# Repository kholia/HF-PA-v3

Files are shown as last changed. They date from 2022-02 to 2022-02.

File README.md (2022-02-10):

### HF-PA-v3

VU3CER's Robust `Class-C / Class-D HF PA` for https://github.com/kholia/Easy-Digital-Beacons-v1
project for the 20m band.

This design aspires to be the standard mW-to-QRP-Gallon HF PA in the ~600 INR
(8 USD) design space.

Design Constraints:

- PCB is to be homebrewed.

- PCB is single-sided - only one layer (side) is available for routing.

- IRF510 MOSFET needs to be on an edge to allow usage of heatsinks.

- Typical external linears (e.g. `PA150 HF Linear Amp`) need 2W minimum to
  function. So we need a minimum of 2W of RF output from our design.

- Minimal part count is strongly preferred. Low cost, and ease of availability
  are strong driving and deciding factors.

  The cost of this HF-PA-v3 system is less than one RD16HHF1 MOSFET ;)

- Reproducibility is a MUST! We focus a lot on this aspect by documenting each,
  and every detail possible.

- Repairability in the field is a MUST!

  Dhiru's finding: Repairing homebrewed PCBs is so much easier, and fun than
  reworking commercial `lead-free` PTH PCBs.

- No moving mechanical parts are allowed in the design - this rules out usage
  of (failure-prone) active cooling options like fans.

Input: Few milliwatts is fine. Note: Si5351's output is around 8-10mW.

Output: 5W+ @ 28v for the 20m band (`QRP Gallon achieved!`) with around ~42%
efficiency. 4.25W+ @ 24v for 20m band (14 MHz) using a single IRF510 with ~33%
to ~43% efficiency. Solid 3W+ at 19v with less than 500mA of total current
consumption. Solid 4W+ at 22v with less than 500mA of total current
consumption. More output is possible via a bit more gate biasing voltage +
increased PA voltages (>= 29v). The `Easy-Digital-Beacons-v1` system itself
consumes 2.49W when operating in the `Beacon Mode`. In comparison to this `v3
HF PA`, https://github.com/kholia/HF-PA-v2/ is more efficient (@ 14 MHz) but is
not as robust. In comparison, ICOM IC-705 efficiency is around 24% - It
consumes around 1.5A @ 13.8v to output 5 watts - Of course, ICOM's PA is a
linear one (with known low efficiencies) whereas ours is a switching one.

Robustness check: The PA works fine with 100% duty cycle for more than 8 hours!
In real-life, WSPR defaults to using ~2-minute TX intervals every 10 minutes.
FT8 is naturally gapped every ~15 seconds, and so on. We have also run FT8 on
this HF PA for more than a day at a time. The whole `HF PA v3` system is
thermally super stable.

Note 1: The output power is software controllable (via `PWM grounding`) for
flexibility.

Note 2: The idea behind making these (and my other) design notes publicly
available is to deliver REPRODUCIBLE, flexible, home-brewable, standardized,
reasonable, and cost-effective solutions for some common problems. I include
many references, simulations, and notes in my projects to enable you to do your
own (better) designs - do share them ;)

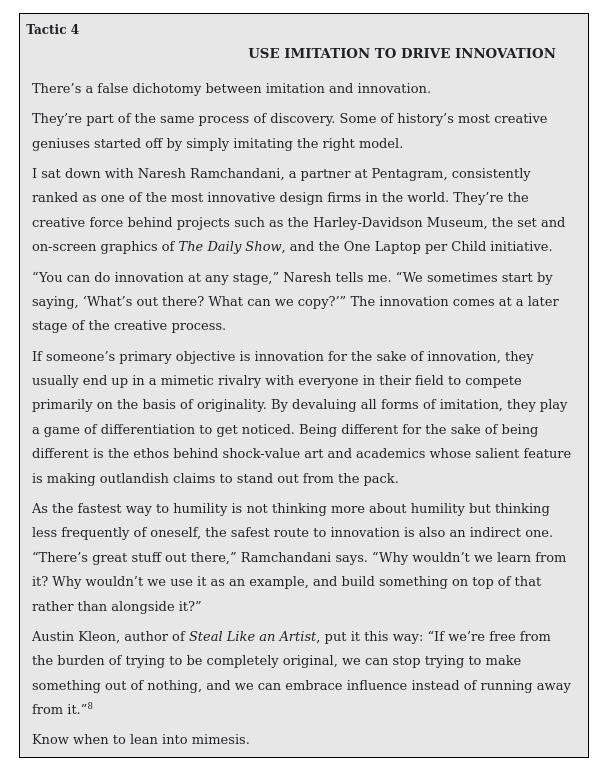
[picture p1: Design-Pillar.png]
Design Pillar


(Image Credit: `Wanting` book by Luke Burgis)

Note 3: All screenshots are clickable and zoomable.

Note 4: Use the `HF-PA-v3-No-Regulator` PCB version included in this
repository. This version doesn't need the 7805 linear regulator.

Please see the older https://github.com/kholia/HF-PA-v2 project for the
power-supply (over-current protected), and LPF designs.

(26-September-2021 UPDATE): [A multi-band (40-20-17-15) version of this PA is now available](https://github.com/kholia/HF-PA-v4/)!

Schematic:

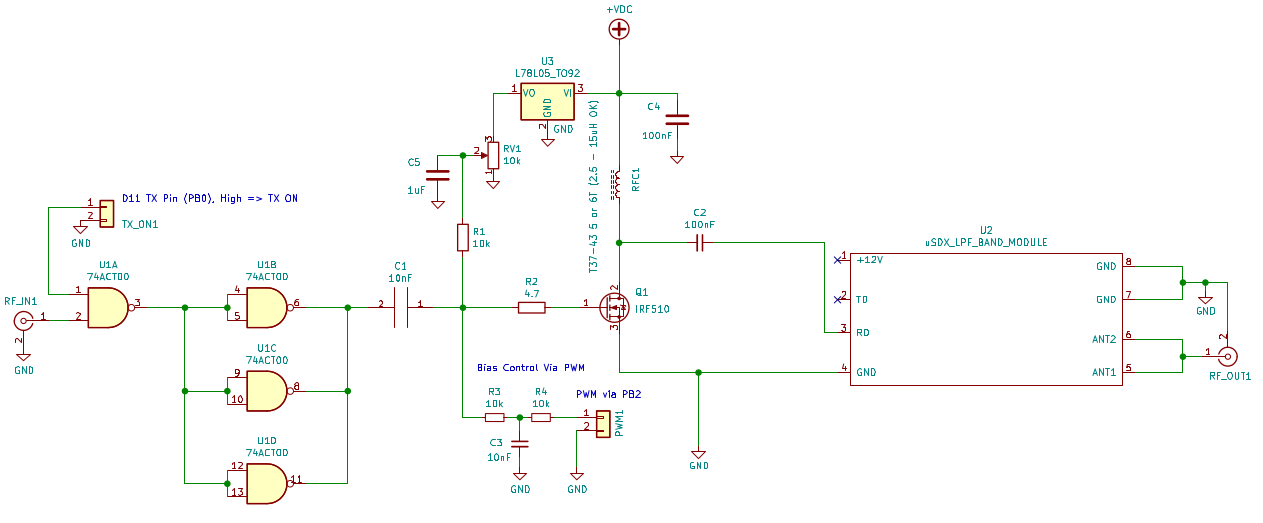
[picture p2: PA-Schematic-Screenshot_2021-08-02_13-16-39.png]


PCB renderings:

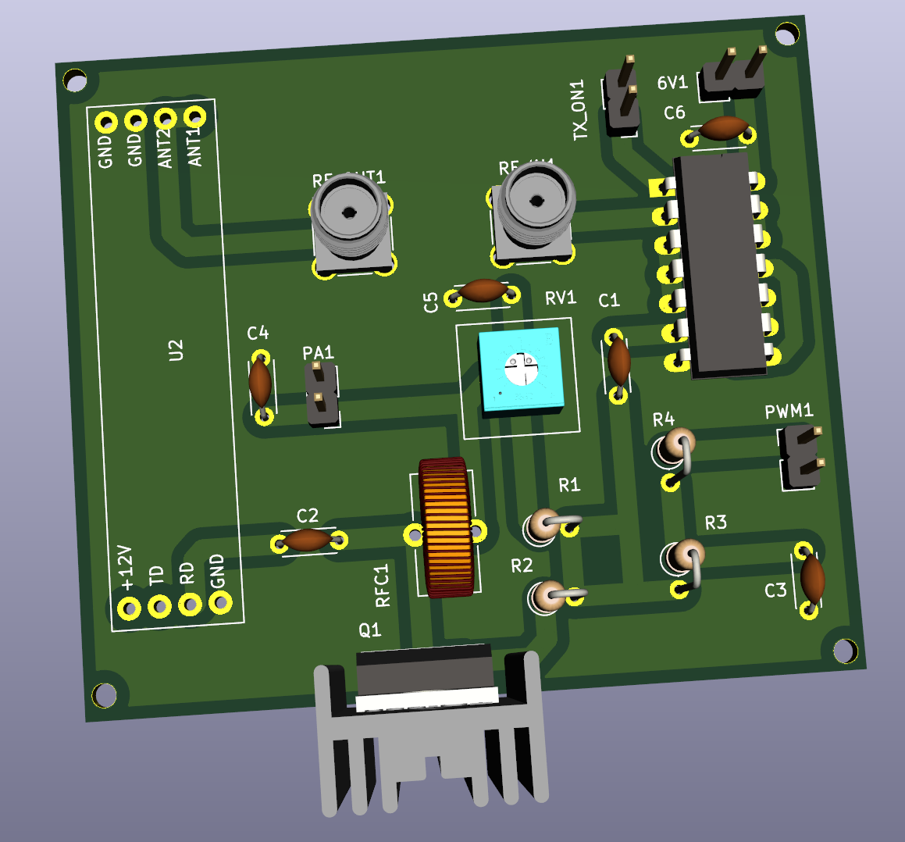
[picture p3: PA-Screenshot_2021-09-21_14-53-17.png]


Pics (or it didn't happen):

5W RF Output @ 28v

Power consumption

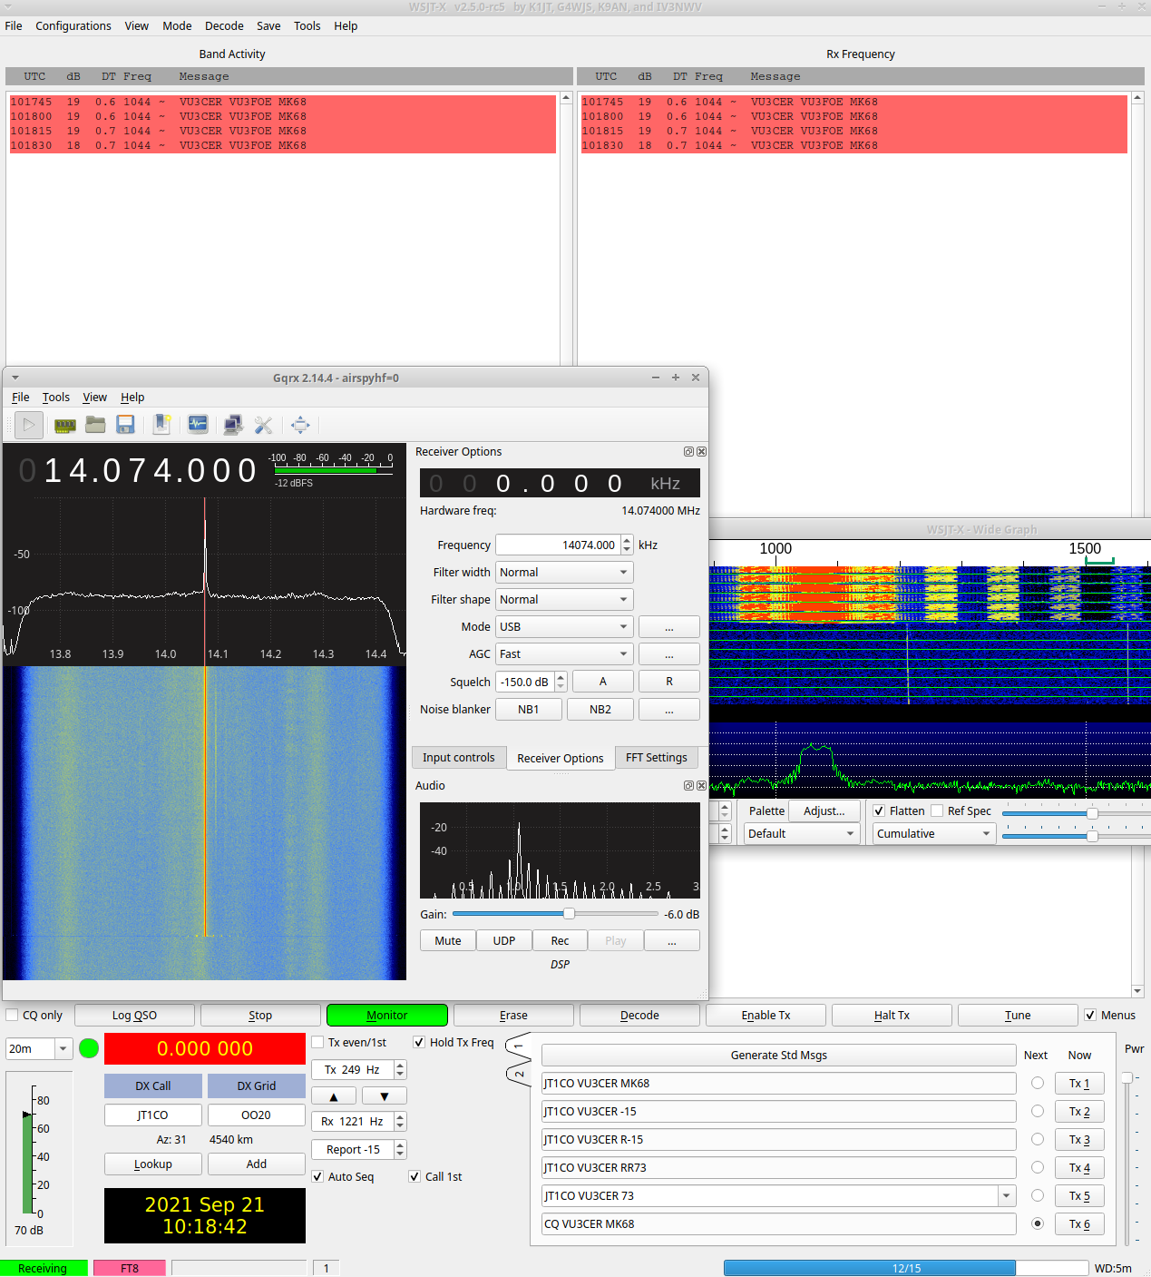
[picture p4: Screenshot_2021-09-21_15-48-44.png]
Whole System Demo


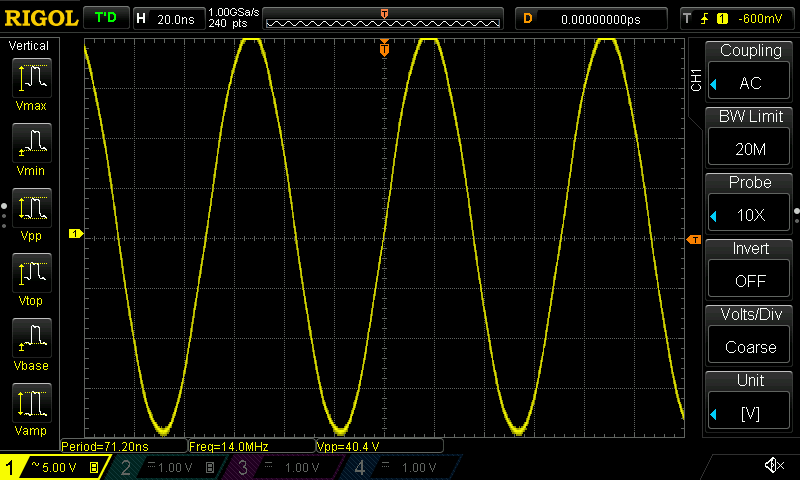
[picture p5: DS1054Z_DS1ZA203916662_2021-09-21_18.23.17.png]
ScopeShot


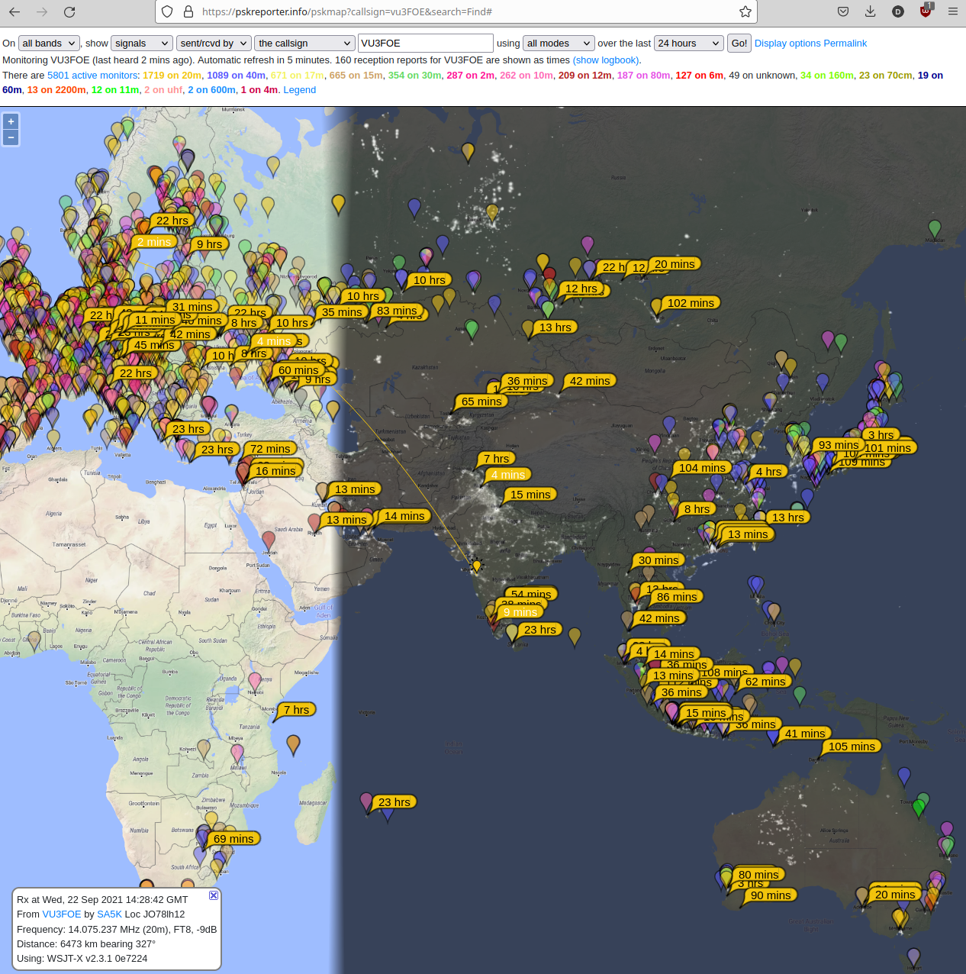
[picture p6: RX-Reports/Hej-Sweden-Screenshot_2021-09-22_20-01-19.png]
RX Report 1 - We are loud enough!


This HF PA is capable of winning some nice awards (e.g. `QRP-ARCI 1000 Mile per Watt award`).

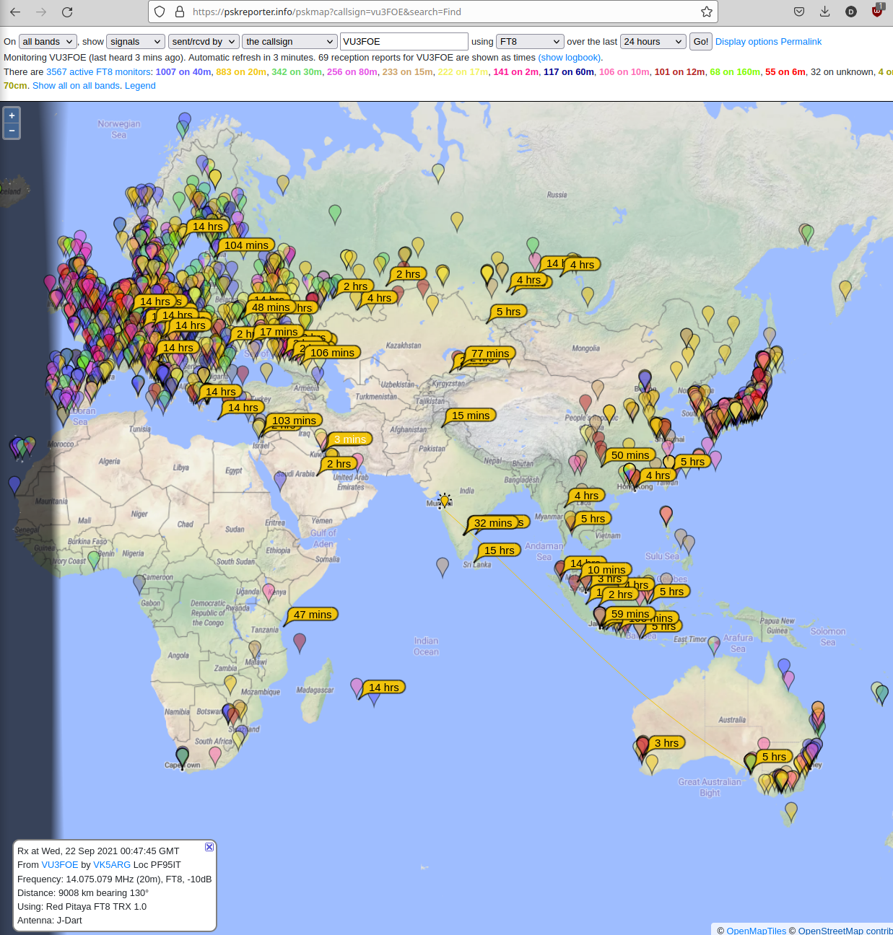
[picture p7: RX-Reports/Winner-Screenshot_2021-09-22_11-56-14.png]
RX Report 2 - w00t!

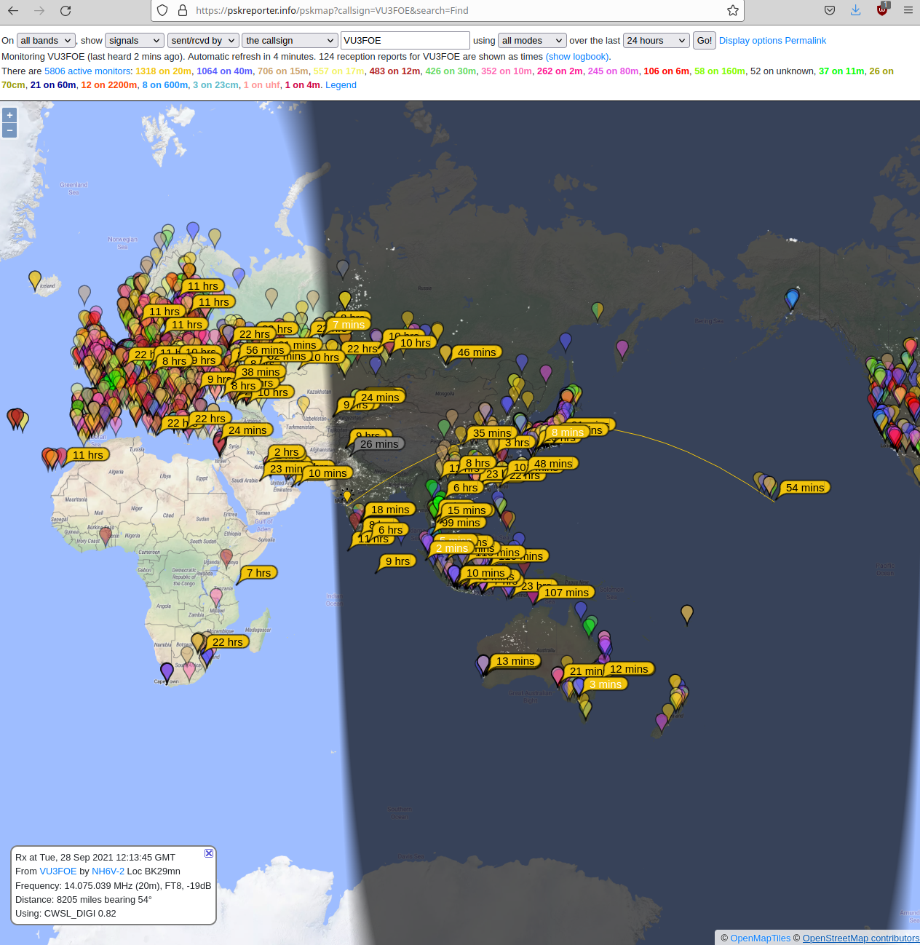
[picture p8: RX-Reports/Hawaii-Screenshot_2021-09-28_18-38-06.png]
RX Report 3 - w00t!

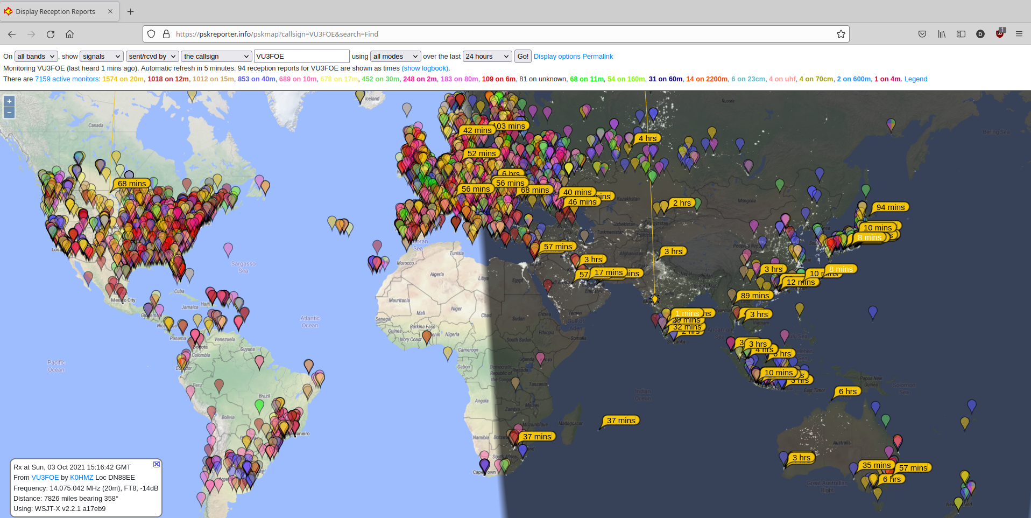
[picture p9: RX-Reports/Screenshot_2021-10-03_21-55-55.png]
RX Report 3 - W land 1

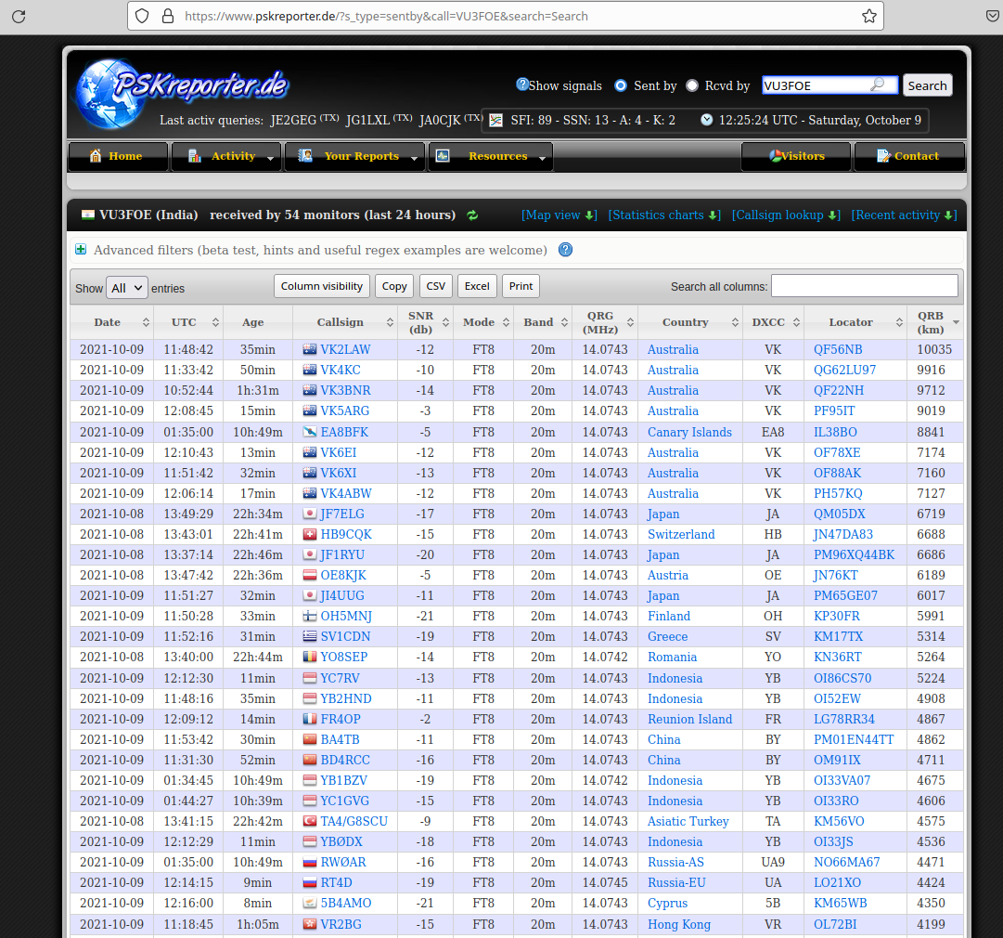
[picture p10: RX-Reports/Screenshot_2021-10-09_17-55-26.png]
RX Report $ - Nice Report


The HF PA is connected to a 20m dipole over 55 meters of HLF-200 coax.

#### PA tuning process

- Remove the MOSFET from the TO-220 socket.

- Set gate bias to 3v. This ensures that IRF510 isn't turned ON - double-check
  this by monitoring the power consumption.

- Connect the MOSFET back, and measure RF output. Happy with the output power? -
  If yes, you are done else follow the next steps.

- Remove the MOSFET, increase the gate bias voltage in very small increments
  (0.1v types).

- Connect the MOSFET back, and measure power consumption without any RF input.
  Ensure that MOSFET remains OFF without any RF input.

- Apply RF input, and measure RF output.

- Repeat these steps as needed.

The [QRP Labs' procedure for bias adjustment](https://www.qrp-labs.com/images/pa/pa_simple_assembly_A4.pdf)
seems to be better.

#### PA BOM

- 1 x SN74ACT00N (TI) - 65 INR

- 1 x IRF510 (Genuine Vishay parts are tried-and-tested) - 35 to 50 INR

  - The `SEC` (`SEC Electronics Inc`) branded IRF510(s) also work great!

  - The `SEC IRF510` performs even better than Vishay's version. This
    particular result will vary between different product batches.

  - IRF510 with `International Rectifier` branding are most likely fake or "new
    old stock" if you are very lucky!

    Note: IR and Infineon have stopped manufacturing IRF510 MOSFETs.

  - AliExpress IRF510(s) are likely to be fake

  - The IR IRF510 gave ~3W versus 5.2W+ from SEC IRF510 versus ~5W from
    Vishay's IRF510!

    Note: The gate threshold voltage can vary even between two samples picked
    from the same manufacturer!

  - The Cgs ("gate capacitance") of a fake IRF510 is typically more than 1000pF
    on a LCR-T4 meter. This value is around ~400pF for genuine IRF510 parts on
    a LCR-T4 meter.

  - Ensure proper sourcing (trusted supply chain, etc) to get genuine parts

- 10K Preset (Potentiometer) Bourns-3386P - 15 to 20 INR

- 4 x 10k Ohm - 0.25W Metal Film Resistor - 10 INR

- 1 x 4.7 Ohm Resistor - 5 INR

- A very large heat sink - 50 to 200 INR - larger heatsink is better!

- 1 x 7805 (TO-220 package from CDIL / ST) Voltage Regulator (Optional but makes PA voltage experiments easier) - 10 INR

- MT3608 2A Max DC-DC Step Up Power Module (Robu) - 60 INR

- 2 x SMA connectors (PCB mount) - 75 INR

- 5 x 100nF (104) Ceramic Capacitor - 15 INR

- 1 x 10nF (103) Ceramic Capacitor - 5 INR

- 1 x uF (105) Ceramic Capacitor - 5 INR

- 1 x FT37-43 (Black Toroid) - 50 INR

  - With 5T of 22 SWG wire, I see 25uH of inductance on my LCR-T4 meter

  - This 5T idea was also found (later) in the NB6M's Miniboots design!

- Misc: Relimate Connectors, Copper Clad PCB, Various Consumables (~100 INR)

- Tools: LCR-T4 Meter (for measuring things), RF Power Meter

- Optional power supply: LM50-20B24 Mornsun SMPS - 24V 2.2A - 52.8W AC/DC SMPS - 700 INR

- PA Total Cost: ~600 INR

#### LPF BOM

- 3 x T37-6 - Yellow Toroid, 1 x T37-2 - Red Toroid (LPF)

- 2 x 180pf, 2 x 390pf, 1 x 30pF NP0 Ceramic Capacitors (LPF caps, Kemet / Vishay / Multicomp Pro)

  Note: The `C0G (NP0)` property is important for filters. Don't doubt this ;)

  Note 2: Get >= 100v rated caps - we are going to output more power!

- 3 meters - Copper Magnetic Winding Wire (22 SWG, ~0.7mm) - 25 INR

- LPF PCB or roll your own

Note: LPF design and values are borrowed from GQRP technical pages (W3NQN), QCX
manual, and uSDX WB2CBA PCB documentation.

#### Power Supply BOM

See https://github.com/kholia/HF-PA-v2.

#### BOM + Equipment Sources

- https://www.semikart.com/ (IRF510, NP0 LPF caps - Kemet and others)

  - Multicomp Pro 100v C0G caps from Element14 are recommended

- https://www.semikart.com/search/SN74ACT00N

- https://www.electronicscomp.com/

  - IRF510 (Vishay), regular caps, ST voltage regulators

- https://www.onlinetps.com/shop/ (IR IRF510, new old stock perhaps?)

- https://www.electroncomponents.com/ (transistors, connectors, consumables, misc)

- https://www.sunrom.com/ (regular ceramic caps, SMA connectors)

- https://projectpoint.in/

  - Transistors, regular caps, voltage regulators, pots / trimmers, MFR resistors, misc

  - 2-Pin High Quality Relimate Connectors (all those 2-pin headers are actually Relimate Connectors)

  - Copper Magnetic Winding Wire

  - 3-Pin Relimate Cable Female to Female (High Quality 2500mA) - 'TO-220 socket'

- Semikart, eBay (`gr_makis`) - Toroids

- https://www.ktron.in/ (SMA connectors)

- [LCR-T4 LCR Meter](https://www.techtonics.in/lcr-t4-12864-lcd-graphical-transistor-tester-resistance-capacitance-esr-scr-meter)

- [AVOID] https://www.fabtolab.com/78l05-voltage-regulator (https://www.ventor.co.in also works)

- https://robu.in/ (voltage boost module)

Note for international buyers: The BOM can be carefully sourced via Mouser and DigiKey.

#### O(Current consumption)

The ESP8266 usually draws a peak current of about 250mA after it wakes up and
then more or less constantly draws around 70mA before it goes back to sleep.

DS3231 -> 5mA

Si5351 -> ~50 to 100mA

PA -> Less than 1 A (rms)

Upper bound -> 1.4A maximum.

#### Tips

MOSFETs are sensitive with regards to ESD and high soldering temperatures. Use
best practices when dealing with MOSFETs and perhaps always ;)

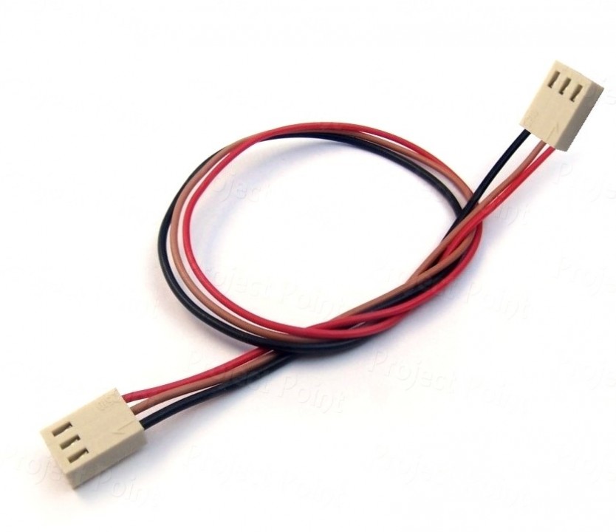
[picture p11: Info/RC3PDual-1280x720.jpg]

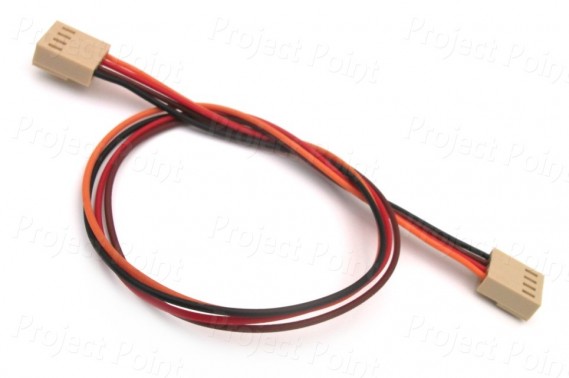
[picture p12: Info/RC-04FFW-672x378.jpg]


By using these `TO-220 Sockets`, we can easily support any MOSFET pinout. This
technique allows usage of `off-pcb` heat sinks with a lot of flexibility. It
also avoids common ESD + MOSFET problems as well. The gate bias can be easily
checked by safely removing the MOSFET from the TO-220 socket. Also, this socket
idea allows us to safely eliminate the LDO from the design.

`SN74ACT00N` can be driven at 6v - this is the secret LU2HES sauce! RF input
drive strength matters the most.

Note: Juan (WJ6C, uSDXn project) reports that IRF530 works better (produces
more power) than IRF510 at higher voltages like 19.5v or 24v. Dhiru's finding
IRF510 works better at 19v (3.25-Watt VS 3-Watt for IRF530). And it should,
right (with its less gate capacitance)?

A burnt 78(L)05 regulator can easily eat up 4-5W of power by itself. If there
is no RF output but power is being consumed then check your linear regulator.

#### Ideas (for v4)

- Be a bit bold, and try Class-D biasing (IRF510 operates in saturation in
  Class-D)!

  Update: Done in https://github.com/kholia/HF-PA-v4 design.

- Try adding a 2N2222 driver stage for output boost to 10W (idea from VU2ASH).

  Update: Done in https://github.com/kholia/HF-PA-v4 design.

- Add support for 15m band. Is this even possible? Keep all leads short (no
  more TO-220 socket idea then it seems).

  Update: Done in https://github.com/kholia/HF-PA-v4 design.

#### References

See [References.md](./References.md).

#### Credits

This design uses ideas from NA5N, Sandeep VU3SXT, PY2OHH, NB6M, LU2HES, Hans
Summers, and VU2ESE (Farhan).

Also see https://github.com/kholia/HF-PA-v2#credits.

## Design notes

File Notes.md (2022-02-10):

In general terms, the PCB industry considers an RF circuit board to be any high
frequency PCB that operates above 100MHz.

IRF510 - The device dissipates 43 watts so as long as the kit doesn't draw more
that about 3.5 amps max at 12 volts, it won't fail. At 5 watts and 50%
efficiency it won't draw more than 1 amp and  can handle full reflected SWR.

https://www.rapidonline.com/Catalogue/Search?Query=CDIL

LED Wemos D1 Mini - The built-in led is on pin D4, and it is inverted.

```
Z=Vcc2 / 2PO
In [7]: (22 * 22) / (2 * 5)
Out[7]: 48.4
```

```
[dhiru@zippy DS1054Z_screen_capture]$ python2 OscScreenGrabLAN.py png 192.168.1.16
Instrument ID: RIGOL TECHNOLOGIES,DS1054Z,DS1ZA203916662,00.04.04.SP3

Receiving screen capture...
Saved file: 'captures/DS1054Z_DS1ZA203916662_2021-09-21_18.23.17.png'
```

From the internet,

7805 -> Without an extra heatsink, you can burn off up to 2W. If you need more
current heatsinks are cheap and effective. Every 11 degrees Celsius cooler you
run your semiconductors, reliability doubles.

- Get the max die temperature from the regulator datasheet

- Get the Theta(j-a) number from the datasheet in degrees C per watt.

- Calculate the power dissipated by your device. Example: 9 volts in, 5 volts
  out at 1 amp would be 4 watts.

- Multiply the watts dissipated by Theta(j-a) to get the temperature rise.

- Add the temperature rise to the maximum ambient temperature the device will
  be exposed to.

- If the number computed in #5 is greater than the max die temperature, then
  you need to use a heatsink or some other way to actively
  cool the device.

- If you use a heatsink, you will use a slightly different set of calculations
  involving the regulator's Theta(j-c) (Not Theta(j-a).

For a 7805 it's 65 C/W junction to air.

This means that if the regulator produces 1 W of heat, the die will be 65
degrees C hotter than the ambient air.  The maximum operating temperature is
125 C. Pune temperature (inside the case) -> 70 c.

Can dissipate -> (125 - 70) / 65 -> 0.84 watts. P = VI. This allows around
100mA of current when input voltage is 14v.

Note: Try the `Small mark` option instead of the regular `Real drill` option in
KiCad.

LTspice notes:

- Download LTspice (Google "Download LTspice"). It's free.

- `~/Documents/LTspiceXVII/lib`

  Extract external components to this path.

- Extract the `contents` of `LTspiceXVII_2019Jan29.zip` (Google for this file) properly to `~/Documents/LTspiceXVII` path.

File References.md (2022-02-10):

#### References

- https://github.com/agustinmartino/wsjt_transceiver
- http://hyse.org/pdf/www.aoc.nrao.edu/~pharden/hobby/_ClassDEF1.pdf
- http://hyse.org/pdf/www.aoc.nrao.edu/~pharden/hobby/_ClassDEF2.pdf
- http://thestone.zone/radio/2020/12/13/multi-watt-amplifier.html
- http://thestone.zone/radio/2020/12/18/gate-driver-amplifier.html
- http://thestone.zone/radio/2021/01/14/capacitors.html
- http://thestone.zone/radio/2021/01/16/minor-enhancements.html
- https://www.g0kla.com/scpa/SimpleCheapPA.php
- https://www.linkedin.com/pulse/rf-pcb-design-rules-manufacturing-process-lisa-chu/
- http://thestone.zone/radio/2021/06/04/attenuator.html
- http://thestone.zone/radio/2021/06/05/power-amplifier.html
- https://on7dq.blogspot.com/2020/12/qcx-mini-measurements.html
- https://www.random-science-tools.com/electronics/dBm-Watts-volts.htm
- https://www.mitsubishielectric.com/semiconductors/php/oSearch.php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
- http://www.carnut.info/WSPR_Tx/WSPR_Tx.htm
- https://sites.google.com/view/andy-g0ftd/iron-fist-transmitter
- https://www.dj0abr.de/english/technik/dds/pa.htm
- https://www.qsl.net/py2ohh/
- https://hf5l.pl/en/transceiver-usdx-with-arduino-nano/#
- http://www.m0rzf.co.uk/PA_Old/index.html
- https://vk3hn.wordpress.com/2019/05/01/summit-prowler-6-a-pocket-sized-ssb-cw-transceiver-for-80-40-30-and-20m/
- http://am-transmitter.blogspot.com/2014/07/protect-your-mosfet-final-stage.html
- https://electronics.stackexchange.com/questions/11583/grounding-a-soldering-iron
- http://hfsignals.blogspot.com/p/25-watt-linear-for-40-and-20.html
- http://www.norcalqrp.org/nb6mminiboots.htm
- https://g4tgj.github.io/5-Band-CW-QRP-Transceiver-Transmit-Board/

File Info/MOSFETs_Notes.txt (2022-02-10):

+++++++++++++++++++

+++++++++++++++++++
Date: Tue, 30 Apr 2002 22:37:32 GMT
From: na5n at zianet.com
To: n2cqr at clix.pt
Cc: qrp-l at lehigh.edu
Subject: [125830] Re: Biasing MOSFETS?
Message-ID: <20020430223732.19795.qmail at zianet.com>
Mime-version: 1.0
Content-type: text/plain; charset="us-ascii"

Bill Meara writes:
> I'm using a little amplifier from Ramsey.  Two MOSFETS in push-pull.
> Broadband linear RF Amp.  I'm using it on 17 meters.

I am not familiar with this specific amplifier, but the principles for
using MOSFET's is the same.

> Problem is that it is getting very hot.  I've increased the size of the
> heatsink, but it still is getting too hot.

There are two types of MOSFET's: RF mosfet's and switching mosfets.  The
RF mosfets are $30-40 each, so seldom seen in amateur work.  That leaves
the cheaper switching mosfet's, such as the IRF510.  These are designed
to be a switch ... ON or OFF.  In between these two states is a small
linear region.  This is where most QRP PA's are supposedly designed to
operate.  In the case of the IRF510, the mosfet "turns on" with a gate
voltage around 3.5-4.0v, and goes fully on (called the "full ohmic on
region") with around 7-8v on the gate.  The exact ON and OFF voltages on
the gate will vary tremendously from one IRF510 to the next.  When you
build an IRF510 PA, you should characterize that particular mosfet so
you know exactly at what gate voltage drain current starts to flow, and
if possible, at what gate voltage the drain current becomes maximum, or
the point of the full-ohmic-on region.

If you spend too much time in the full-ohmic-on region, you are drawing
excessive current not being transformed to output power, which is
dissipated across the source-drain junction ... that is, excessive HEATING
of the IRF510.

> I'm wondering if there would be any benefit to moving the biasing diode so
> that it would be in physical contact with the heat sink.  This worked
> wonders in stabilizing a BJT amp, and in keeping it cooler -- I'm wondering
> if this would also work with MOSFETS.

Per the above, it is more important to characterize the biasing points of
your IRF510's.  You'll need to monitor BOTH the drain and gate voltages
simultaneously with either a DVM and/or an oscope.  With no gate voltage,
the IRF510 will be OFF, such that you will have +12V on the drain (or
whatever your raw Vcc is).

Connect a 10K or so pot between ground and +12, such that the wiper then
will go from 0V to +12v.  Connect the wiper to the gate.  Initially set it
to 0v and record the drain voltage.  Say it is +12v.

Now increase the voltage on the gate until the drain voltage begins to
drop by the smallest amount you can detect.  Usually 100-200mV should be
obvious on most DVM's or scopes.  Say this happens with the gate voltage
at 3.8v.  This is the gate turn-ON voltage: 3.8v

Now increase the gate voltage and watch the drain voltage go down ...
10v, 8v, 6v, etc.  Be quick at this.  You may need to turn the gate
voltage to 0v if the IRF510 starts getting too hot doing this before doing
it again.  What you are looking for is increasing the gate voltage and
watching for the point where the drain voltage no longer gets any lower.
Say this happens with a gate voltage of 7.8v and a drain voltage of 1v.
If you increase the gate voltage to 8v, the drain voltage stays at 1v.
You are defining the dynamic range of the LINEAR region.  In this case,
the linear region is a gate voltage from 3.8v to 7.8v ... producing a
drain voltage that varies from +12v down to +1v.  Another way to look at
it is the mosfet turns ON with a gate voltage of 3.8v (which means it is
OFF below 3.8v), and the "switch" (the IRF510) is fully ON with a gate
voltage of 7.8v.  This is the gate voltage range you MUST operate within!
But remember, with the gate voltage at 7.8v, producing a drain voltage of
1v, you are now drawing FULL CURRENT, which for the IRF510 is around 5A!
(Assuming your power supply can provide that).

For accuracy, there is one additional test you need to perform.  For a
typical 5W QRP PA running class C (50% efficiency), a drain current of
about 1A is usually required.  In this case, 12V x 1A = 12W input power,
yielding an efficiency of 5W/12W = 42% (fairly typical inspite of the
amazing efficiency claims made by some).  How much current does your rig
draw to make 5W?  Figure out the efficiency yourself using the above.
Subtract the receive current from the transmit current to be a purist.

But this 1A is rms, meaning the IFR510 will be drawing about 1.5A on the
peaks (1A x 1.414).  So you need to find out at what gate voltage produces
a drain current flow of 1.5A.  To do this, you must monitor the drain
current flow (either in the drain lead, or between the power supply and
the rig, providing you subtract out the receive or standby current on
key  up).

Let's say you parallel some resistors to achieve 1-ohm in the drain lead.
This means when you drop 1.5V across this 1-ohm resistor, your drain
current is about 1.5A.

Now increase your pot/gate voltage again until you see your 1.5V drop
across the 1-ohm resistor, identifying 1.5A of drain current.  Say this
occurs at 7.4v on the gate.  This identifies the true dynamic range you
need to operate your IRF510 inside of ... a gate voltage from 3.8V
(turn ON) to 7.4v for 1.5A peak of drain current.

HERE'S THE BIGGEST MISTAKE MOST IRF510 CIRCUITS MAKE:
=====================================================

You go keydown for transmit, and adjust the bias for 5W output.  When you
go keyup, the IRF510 should TURN OFF.  But if the bias is set too high,
above 3.8v gate turn on in this example, your IRF510 will be drawing
current, perhaps several hundred mA of current if you don't check.  This,
of course, is wasted power and needlessly heating up your IRF510.

IRF510's are SWITCHING MOSFET'S ... there is absolutely NO NEED to set
this so-called "idling current" in a mosfet.  On keyup, there should be
NONE, ZERO, ZIP drain current flowing in the IRF510.

If you set your bias for 5W out, and you still have drain current flowing
on key-up, your problem is simple: INSUFFICIENT GATE DRIVE -- not biasing.
You do not have enough peak-to-peak RF drive going to the gate.  This is
the biggest problem I've seen with most published IRF510 circuits ...
insufficient gate drive!

Back to our example, the gate turns ON at 3.8v and the drain draws 1.5A
at 7.4V.  This is 3.6v difference.  Your RF drive needs to be AT LEAST
twice this! (or 7.2Vpp).

MY RECOMMENDATION with the above example, is to bias the gate around
0.5v below the gate turn on voltage ... or 3.8 - 0.5v = 3.3V.  With no
input signal, this will ensure the IRF510 is completely turned off
(with the gate turn on voltage of 3.8v).  The input RF drive signal should
be capacitively coupled, so that with no RF drive, the gate voltage is
this 3.3v, and the IRF510 is turned OFF.

For proper class C biasing, your input drive should be twice your gate
input biasing range, that is, twice the 3.8v (turn ON) to 7.4v (Id=1.5A),
or about 7.2Vpp RF drive at the driver output, feeding the coupling
capacitor between the drive and gate input circuit.  The first 3.8v will
do nothing (except help charge up the gate-source capacitance ... about
150pF).  Then when it exceeds the 3.8v bias, the IRF510 will begin to
conduct.  When the input drive reaches the maximum of 7.2v, this will be
the MOMENTARY point of maximum 1.5A drain current, corresponding to about
1A rms drain current.

So to properly bias an IRF510, you need to know at what gate voltage
drain current BEGINS to flow, at what gate voltage produces about 1.5A
of drain current, and at what gate voltage causes FULL current flow.
In most IRF510's, the difference in gate voltage between 1.5A and full
drain current is 0.5V or even less.  Fairly critical.

The last problem, of course, is if you have too much gate drive, say
8-9V peak.  This is because (in our example), once the gate voltage
exceeds the 7.4v (1.5A drain current point), much above that, the
IRF510 will be drawing it's full 5A of current over some portion of the
input sinewave, usually 10-25% of the cycle.  This excess power does
two bad things:
1) It saturates the toroidal core being used in the drain circuit for
   the RFC or transformer primarily (usually a 1:4 bifilar wound
   transformer).  This inductance can not get rid of all of its stored
   up current into the output filter before the next drain current cycle
   begins if it goes into core saturation.  A T50-43 core will saturate
   around 2A peak current.
2) The excess current has no place to go except to dissipate in the form
   of heat across the drain-source junction.  This will make the IRF510
   VERY, VERY HOT in short order.  The kind of heat that removes your
   finger print!

In this full-drain current (full-ohmic on) condition, another bad thing
needs to be pointed out:  We know that the approximate output resistance
of any PA transistor or mosfet is the famous RL=Vcc^2/2Po, which equates
to about 14 ohms at 12V and 5W output.  When you enter the full ohmic-on
region, the output resistance then becomes the Rds of the IRF510, which
is about 0.4ohms.  Drop nearly 12V at 5A across a 0.4 ohm resistor, and
buddy -- you're making some major heat. (P=EI = 12V x 5A = 60Watts!).
The maximum power dissipation of an IRF510 is about 40W.  Ooops ...
something has got to give.  Poof - there goes your IRF510 after about
5 seconds of keydown.

So, for each IRF510 you build a PA out of, characterize the gate voltage
required for gate turn on, 1.5A of drain current, and where it goes into
it's full ohmic-on region (full drain current flow).  This defines your
effective dynamic range of RF drive, and the safe operating area you
should remain within.

If you built an IRF510 from somebody's article that says to set 50mA or so
of idle current on key-up, immediately drop the gate bias a bit until
NO DRAIN CURRENT flows.  And if you can't get 5W out at this point, then
increase your RF drive.  Or, if it's getting too hot, then check that
you don't have too much drive, drawing more than 1A rms, or that the
gate is not exceeding 8V (or whatever you measured) on the peaks.

MOSFET PA's make neat amplifiers, but due to the large variations from
one device to the next, they are not as reliable to build as a BJT
PA using a 2SC2078 or something.  This is why each IRF510 should be
characterized before building the PA to establish the proper bias point.

> What do you say? Would this be a cool move or what?

By setting the PROPER BIAS POINT AND RF DRIVE, you shouldn't have to
piddle around with diode temperature compensation or bias feedback
networks to make the IRF510 work properly.

It's OK for the IRF510 to get fairly hot after 5-10 seconds of keydown
with a class C 5W PA, but if you're leaving finger prints ... then it's
way too hot and it is not properly biased or driven.

72, Paul NA5N

+++++++++++++++++++
Date: Wed, 01 May 2002 23:42:46 GMT
From: na5n at zianet.com
To: qrp-l at lehigh.edu
Subject: [125876] Biasing MOS-FET

Karl F. Larsen writes:

>       For CW where the signal is on or off, you should bias the devices
> for no drain current in the off condition,

TRUE

> and drive the devices hard enough to saturate drain current when on.
> This will result in the highest efficiency and of course, least power to > heating.

FALSE.  This is one of the major points of yesterday's post.  You want to
AVOID driving a mosfet so hard that the drain current saturates, because
in the case of the IRF510, you will suddenly be drawing 5-6 amps and your
output load resistance drops to 0.4 ohms - making an impedance match to
your 50-ohm filter network impossible.  The 5-6A of drain current, even
if only 10-20% of the RF cycle, raises your average drain current over
rms by that same percentage, and lowers your efficiency by the same
percentage.  And with 5-6A flowing through the IRF510, even 10-20% of the
time, is still a lot of power being converted to nothing but heat inside
the IRF510.  You want to avoid saturating the drain current at all costs.

Except, of course, in the case of Class E, which exploits operating the
IRF510 in the saturated drain current region.  But here, you are not
driving the mosfet with a sinewave, but rather fairly narrow "pulses" to
convert the 5-6A of drain current to the desired 1A average current.
Actually, it ends up being less than that for efficiencies in the
80-90% range.  But that is also due to doing business a bit different
in the output filter and how one impedance matches the IRF510 to the
50-ohm filter.  But in any case, you never drive a mosfet in class D, E
or F with a sinewave.

> need a good filter on the output. If your using push-pull your filter job
> is easier because even harmonics are very low.

TRUE.  Filtering does need to be more precisely matched to a mosfet PA
depending upon the exact class of operation it is in.

> I would be careful not to overdrive the amp and flat top.

Well, this is exactly my point, and seemingly opposite of what is said
above about "driving the amp into the saturated drain current region."
There is no way to avoid flat topping when you are in the saturation
region.

This is not in any way an attack on Karl, but to emphasize and explain
why a mosfet class c amplifier, being fed with a sine wave, should never
be allowed to drive the mosfet into saturated drain current.  This is a
common mistake made by those trying to build mosfet PA's, and a major
reason why the mosfet's go poof, or get extremely hot, or sound chirpy,
because when you enter the saturated region, it's trying to draw almost
everything your power supply has to offer.  Even batteries can groan when
the load changes from 1A to 5A almost instantaneously.

72, Paul NA5N

+++++++++++++++++++
Date: Wed, 1 May 2002 00:55:29 -0700
From: "Bob Okas" <vintage2 at earthlink.net>
To: <na5n at zianet.com>, <n2cqr at clix.pt>, <qrp-l at lehigh.edu>
Subject: [125852] Re: Biasing MOSFETS?

Hi Paul,

    Kudos for such a lucid description of Class C mosfet biasing. I've
squirreled it away in my na5n folder. However, I do wish to point out that
the original poster was describing a mosfet push pull *linear* amp.
Remembering Bill Meara's proclivity for SSB operation on 17m, I suspect he's
looking to boost his phone signal. If, say, the Ramsey amp was designed for
operation in the Class AB-ish region, then some current would be drawn by
the finals during those moments of non-speech keydown.

    I've read W1HUE's article, <http://www.qrparci.org/east/Q_MODS5.html>,
which dispels the notion I've held that Mosfets have an absolute negative
temperature coefficient that reduces the device gain as the junction
temperature increases. So, thermally attaching the biasing diode to the
heatsink should help, provided that the bias is not initially too high. I
wonder if Bill could tell us what the gate bias voltage is and the part
number of those devices? Is there a bias adjustment?

73,
Bob - W3CD

+++++++++++++++++++
Date: Wed, 01 May 2002 14:25:04 -0400
From: "Jim Kortge, K8IQY" <jokortge at prodigy.net>
To: WD8CIV at worldnet.att.net
Cc: qrp-l at lehigh.edu
Subject: [125861] Re: Biasing Mosfets

At 01:38 PM 5/1/02 -0400, you wrote:

>Folks,
>
>Seeing the discussion on MOSFETs has got me thinking (always a dangerous
>activity) - what is the practical upper frequency limit of an IRF510 (or
>two) used as a final?
>
>Dave

Dave,

Using properly designed feedback networks, they will easily go up
to 17 meters.  I use a pair of MTP3055E MOSFETs in a small linear
amplifier that I designed and built for 40 and 17.  I get about
12 watts out on 40 and about 10 on 17.  The feedback circuits were
optimized for 17 meter operation.  I believe the QRP Plus rig used
an IRF510 in the final up to 6 or 10 meters, but I suspect the power
output suffers terribly up that high.

72,

Jim, K8IQY

+++++++++++++++++++
Date: Wed, 01 May 2002 19:11:49 -0100
From: Bill Meara <n2cqr at clix.pt>
To: vintage2 at earthlink.net
Cc: qrp-l at lehigh.edu
Subject: [125862] Re: Biasing MOSFETS?

At 12:55 AM 5/1/02 -0700, you wrote:
>Hi Paul,
>
>    Kudos for such a lucid description of Class C mosfet biasing. I've
>squirreled it away in my na5n folder. However, I do wish to point out that
>the original poster was describing a mosfet push pull *linear* amp.
>Remembering Bill Meara's proclivity for SSB operation on 17m, I suspect he's
>looking to boost his phone signal. If, say, the Ramsey amp was designed for
>operation in the Class AB-ish region, then some current would be drawn by
>the finals during those moments of non-speech keydown.
>
>    I've read W1HUE's article, <http://www.qrparci.org/east/Q_MODS5.html>,
>which dispels the notion I've held that Mosfets have an absolute negative
>temperature coefficient that reduces the device gain as the junction
>temperature increases. So, thermally attaching the biasing diode to the
>heatsink should help, provided that the bias is not initially too high. I
>wonder if Bill could tell us what the gate bias voltage is and the part
>number of those devices? Is there a bias adjustment?

Bob:  The devices in the Ramsey Amp are MTP3055E.  I'm guessing that they
are switching MOSFETS similar to those described in Paul's excellent post.

Yea, biasing is more complicated once you leave Class C.  The Ramsey manual
advises you to monitor the current and adjust bias (no signal in) for 250
milliamps.  They have a test point in the bias circuit, and with 250 ma,
they say that point should read 3.2 to 3.5 volts.  I found that the voltage
reading I got was a bit higher -- about 4.4 volts. This confirms what Paul
said about variations in bias points.

I notice that as the amp gets warm, the idle current starts going up.  Mine
goes to about 340 milliamps after a standard length CQ.  I now have a larger
heat sink and a big old fan (tube type!) on the amp, so it is under control,
but I'd be happier if the idle current stayed put.

I'm wondering how low I can go with the idle current before I start getting
non-linear. Lower idle current would obviously keep things cooler.

I also saw the temp stabilization article you cited. Looked kind of
complicated to me. I wonder if just putting the diode on the heat sink would
work just as well. I may give this a try.

The amp is working well. Takes me from about 1 watt PEP to about 15-18 watts
PEP. "Stand by while I kick in the lin-yer OM!"  Lots of fun.

73  Bill  CU2JL   N2CQR

+++++++++++++++++++
Date: Wed, 1 May 2002 14:57:46 -0600 (MDT)
From: "Karl F. Larsen" <k5di at zianet.com>
To: qrp-l at lehigh.edu
Subject: [125867] Biasing MOS-FET

        To my way of thinking the bias point is defined by whether the
amplifier is linear or not. By linear I mean if the input is 10% 50% or
100% of maximum output the output follows that with good accuracy.

        For CW where the signal is on or off, you should bias the devices
for no drain current in the off condition, and drive the devices hard
enough to saturate drain current when on. This will result in the highest
efficiency and of course, least power to heating. Your for sure going to
need a good filter on the output. If your using push-pull your filter job
is easier because even harmonics are very low.

        Now you start to bias the devices into conduction when you need a
linear amp. This increases loss to heat and the devices get hot. 500 Ma at
12 volts is 6 watts of constant heat dissipation in the device. If you
think you need 2 amps of drain bias then the linearity is great but the
amp gets real hot.

        If I were doing this I would try Class B operation. Here there is
just a tiny drain current when no signal is present. I would be careful
not to overdrive the amp and flat top. This is very possible to set up.

--
Yours Truly,

         - Karl F. Larsen, k5di at arrl.net  (505) 524-3303  -
                        http://www.zianet.com/k5di/

+++++++++++++++++++
Date: Wed, 1 May 2002 19:15:35 -0500
From: Nick Kennedy <nkennedy at tcainternet.com>
To: "'na5n at zianet.com'" <na5n at zianet.com>,
        Low Power Amateur Radio Discussion <qrp-l at Lehigh.EDU>
Subject: [125881] RE: Biasing MOS-FET

-----Original Message-----
From:   na5n at zianet.com [SMTP:na5n at zianet.com]
Sent:   Wednesday, May 01, 2002 6:43 PM
To:     Low Power Amateur Radio Discussion
Subject:        Biasing MOS-FET

"You want to AVOID driving a mosfet so hard that the drain current
saturates, because
in the case of the IRF510, you will suddenly be drawing 5-6 amps and your
output load resistance drops to 0.4 ohms - making an impedance match to
your 50-ohm filter network impossible."

Hmmm ... I always thought you don't impedance match the output device to
the load in Class C.  And that to do so would reduce the efficiency to 50%.
 Or at least, restrict it to no greater than that value.

And if you don't drive the Class C amp such as its conduction is
approximately a square wave, aren't you dwelling in the ohmic region you
said you wanted to avoid?

72--Nick, WA5BDU

... confused in Arkansas

+++++++++++++++++++
Date: Thu, 2 May 2002 05:45:03 -0600 (MDT)
From: "Karl F. Larsen" <k5di at zianet.com>
To: na5n at zianet.com
Cc: Low Power Amateur Radio Discussion <qrp-l at Lehigh.EDU>
Subject: [125895] Re: Biasing MOS-FET

Let me address just one issue Paul.

On Wed, 1 May 2002 na5n at zianet.com wrote:

>
> Karl F. Larsen writes:
>
> >     For CW where the signal is on or off, you should bias the devices
> > for no drain current in the off condition,
>
> TRUE
>
> > and drive the devices hard enough to saturate drain current when on.
> > This will result in the highest efficiency and of course, least power to > heating.
>
> FALSE.  This is one of the major points of yesterday's post.  You want to
> AVOID driving a mosfet so hard that the drain current saturates, because
> in the case of the IRF510, you will suddenly be drawing 5-6 amps and your
> output load resistance drops to 0.4 ohms - making an impedance match to
> your 50-ohm filter network impossible.  The 5-6A of drain current, even
> if only 10-20% of the RF cycle, raises your average drain current over
> rms by that same percentage, and lowers your efficiency by the same
> percentage.  And with 5-6A flowing through the IRF510, even 10-20% of the
> time, is still a lot of power being converted to nothing but heat inside
> the IRF510.  You want to avoid saturating the drain current at all costs.
>

        I agree that if you saturate a fet the current is a maximum amount
the device can draw but this is a DC analysis of the output impedance.
Looking at the RF impedance it's actually defined from the median
impedance between cutoff which is very high and effective zero in
saturation. Actually you need a set of load lines like we had in the old
tube days. Might be fun to make them and see how they look.

        If the IRF510 has a gate type responce to it's input then it won't
work very well in RF service. I'm pretty sure that's what the device
is used for in the mass market.

Until we can get some AC analysis of this device I'm not ready to say that
you can't match the IRF510 output because I'm doing that with my SMK-1 5
watt amp which uses this device... and it works. Doesn't get hot at all.

--
Yours Truly,

         - Karl F. Larsen, k5di at arrl.net  (505) 524-3303  -

+++++++++++++++++++
Date: Thu, 2 May 2002 12:53:11 -0700
From: "Glen Leinweber" <leinwebe at mcmail.cis.mcmaster.ca>
To: "David Hinerman" <WD8CIV at worldnet.att.net>
Cc: "qrp-l" <qrp-l at lehigh.edu>
Subject: [125904] HF MOSfet amps - capacitance
Message-ID: <000801c1f212$fd54a2c0$07ea7182 at mcmaster.ca>
MIME-Version: 1.0
Content-Type: text/plain;
        charset="iso-8859-1"
Content-Transfer-Encoding: 7bit

Dave Hineman mentions that not all MOSfets are
equal - for example, the IRF840 has an input
capacitance at the gate of 1300 pf, while the
IRF510 that we commonly see has 135 pf.

Don't take these numbers as absolute. Capacitance
changes with bias, and doesn't include Miller
capacitance from gate to drain.

Why does capacitance change from FET to FET?
These devices have many hundreds or thousands
of FETs all running in parallel, right on that single
chip. The heftier FETs have more in parallel than
the less-powerful ones. You can usually tell by the
full-ON channel resistance....when this number is
a small fraction of an ohm, its a BIG device, with
a lotta fets in parallel. The IRF510 has a channel
resistance (fully on) of about half an ohm. Not
so many fets.
    More parallel fets means more capacitance -
capacitances in parallel add. Its that simple. We
should use MOSfets in HF amps with low
capacitance - they're easier to drive. The IRF510
on-resistance of half an ohm is plenty low enough
for QRP with 12v supply. For a really powerful amp,
you'd have to use a higher supply voltage, or a
heftier MOSfet (and be prepared to drive its
larger input capacitance with a more powerful
driver stage).

    Logic-level MOSfets can help too - they turn
on with lower bias voltages, and are FULLY on
when the gate is only +5v (instead of +10v for
non-logic-level MOSfets).
    If you only have to charge gate capacitance
to 5v instead of 10v, less drive power is required.
So a IRFL510 is better than standard IRF510.

+++++++++++++++++++

Date: Thu, 2 May 2002 19:09:02 -0700
From: "Glen Leinweber" <leinwebe at mcmail.cis.mcmaster.ca>
To: <na5n at zianet.com>
Cc: "qrp-l" <qrp-l at lehigh.edu>
Subject: [125915] Re: Biasing MOSFETS?

Paul suggest some great ways to characterize a MOSfet's
biasing characteristics, when used as a RF power amp.

Paul also suggests some bad things that can happen when
over-driving a MOSfet...one of which is saturation of the
RFC choke feeding in DC power. Yes, that's bad, wasting
power in heat (in the choke).
    But you won't waste much power heating the FET.
When you overdrive a MOSfet (gate voltage swinging up
over approx +7v), it does turn on hard, and looks like
a small, fractional-ohm resistor. But this only happens
for a fraction of a microsecond. During that time, the
MOSfet dissipates very little power, since its drain voltage
is very nearly zero - same as the source. No voltage
across the FET?...no power dissipated - even though
there may be a lotta current running thru.
    Yes, if you LEAVE the gate at +8v, current builds
after a few microseconds and something soon gives up
the smoke - maybe the FET, maybe the choke. But
that's not how it runs in an amp - the FET only asks
for current in short, sub-microsecond pulses. So Paul's
smoky scenario when overdriving is not likely, if you
stay within reasonable limits....

As long as the choke can stand the current, overdriving
a MOSfet likely improves efficiency, making the FET
run cooler. There'll be a bit more current in the choke,
and a bit more current in the FET, but that's turned over
to the filter between FET and antenna to be turned into
useful RF power.
The real neat thing about a switching type PA, is that
when the fet is hard ON, with its drain clamped firmly
down at zero volts, its not dissipating much power.
Yes, current is building in the choke, and you can't
stay here too long. We'll only be here for half a cycle.
Then the FET goes OFF - bang - current drops to
zero and the drain voltage starts swinging up. But
again, the FET dissipates no power, because there's
no current thru it. Beauty! When its ON - little power
dissipated - when its OFF - no power dissipated.
Things aren't THAT perfect - the FET takes a bit of
time to switch ON & OFF. During that switching time
it dissipates power. And some of the drive power
coming in the gate goes into heat too. And when
its ON, that small ohmic resistance dissipates a
bit of power (an amp thru half ohm is half watt, and
for only half the time - a total of quarter watt).

Overdriving has limits: your gate voltage swing must
stay below a swing from +20 to -20 v, or you'll puncture
the gate oxide (blown fet). And overdriving too far
wastes drive power too.

+++++++++++++++++++
Date: Fri, 03 May 2002 15:15:14 GMT
From: na5n at zianet.com
To: qrp-l at lehigh.edu
Subject: [125927] More MOSFET stuff

Gang,
Glen's post is excellent, and it addresses some of the discussion I have
been having with several of you privately, worth repeating here.

This discussion began about questioning why a certain MOSFET PA was
running so darn hot.  This is usually an indication of poor biasing or
overdriving the gate ... that is, for some percentage of the input RF,
you are drawing full drain current.  If this is a relatively small part
of the input sinewave, it's usually not a problem.  Helping people with
their mosfet PA's over the years, particularly those who built the
38-Special add-on mosfet PA (which was initially poorly biased), the main
problem I see is people increasing the gate bias to achieve maximum
output power.  Problem with this approach is when the input drive goes
to zero, the gate may be sitting with 4v or so bias, sufficient to keep
the mosfet drawing significant current.  With full input drive, it may
drive the gate into the 7-8v region allowing full drain current.  With a
SINEWAVE, if this full-drain current is occurring for too long each cycle,
you can dissipate a lot of power within the mosfet, which if severe
enough, will of course cause damage to the device.  Therefore in my
original post, I was trying to describe how to determine the useful
dynamic range of a mosfet gate drive, since every mosfet tends to have it's
own parameters.

A second point: while I mentioned that when entering the full drain
current region, the drain-source resistance drops to about 0.4 ohms for
the IRF510, this occurs ONLY for the period of time of full drain current,
not all the time.  The overall output resistance of the mosfet will be the
AVERAGE of the resistances seen over each cycle, and thus will be a bit
lower than the RL=Vcc^2/2Po value, not 0.4 ohms.  Of course the longer
you stay in the full drain current region, the lower your AVERAGE output
resistance will be.  Likewise, when in the full drain current region,
drawing around 5A, the AVERAGE drain current for each cycle will be
closer to the 1A (at 5W) level.  Again, the longer you stay in the
full drain current region, the higher the AVERAGE drain current will be,
but will never be excessively above 1A average.  The problem, however, is
the momentary "spikes" of 5A drain current can put a large strain on the
RFC feeding dc to the drain, possibly causing core saturation, and
another set of problems for the PA and output filtering.

Keep in mind, the above is based on feeding the mosfet with a SINEWAVE
input.  The more efficient mosfet PA's, such as those discussed by Glen,
are based on driving the mosfet with SQUAREWAVES.  This helps assure that
when the gate signal goes positive, driving the device into full drain
current, the drain voltage is very close to 0V for very little heat
dissipation in the device.  This is difficult to achieve with a sinewave
input, as there is a delay between the gate drive signal and the drain
signal due to charging up the relatively large (150pF) gate input
capacitance.  With a square wave, you are charging up this gate capacitance
very quickly, while with a sinewave input, you are charging it more
slowly, causing a longer delay, such that it is difficult to get maximum
drain current to coincide with zero drain voltage for a very long.  With
a squarewave drive, max. drain current at 0V drain voltage can exist for
20-30% of the cycle, in effect, expending virtually no power.

With a sinewave drive, you vary the mosfet output power by controlling
the peak-peak voltage of the gate drive.  The more drive, the more output
power (until you saturate in the full drain current region).  With a
squarewave drive, you control output power by controlling the duty cycle
of the squarewave.  That is, if the drive signal is "hi" for 10% of the
cycle, you are drawing full drain current for only 10% of the time and a
relatively low average output power results.  Increasing the input duty
cycle to 30%, means you are drawing full drain current for 30% of the
time, for significantly more output power.  This is called PWM, or "pulse
width modulation" technique.  In this case, we are not changing the
pulse width fast for the purpose of modulating the carrier, but changing
the pulse width on very slow time scales to change the output power.  On
a typical class E PA I have built using an IRF510, output power varies
from about 3W to 9W by varying the input duty cycle from about 10-40%.
Less than 10%, the mosfet gets unstable with high phase noise -- above
40%, drain current starts flowing so much of the time, you can stray
away from having full drain current at 0V drain voltage, and thus the
efficiency starts to suffer.  In the 10-40% drive, efficiencies in the
80% range are seen.  This means the IRF510 is comfortably warm even with
several minutes of solid keydown.  It also means it's drawing far less
battery current to make 5W than a PA running 50%, obviously.

I'm glad many of you are finding this discussion useful and informative.
Feel free to share with us your experiences.  Mosfet's are fun devices,
and capable of making a nice QRP PA in a properly designed circuit.  And
many of these points discussed by myself and others is why some people
claim they are making 5W and the IRF510 is scarcely warm, while others
are cooking eggs at 3W.

72, Paul NA5N

++++++++++++++++
Date: Mon, 6 May 2002 12:48:52 -0500
From: "Walter AG5P" <walter at accessus.net>
To: "Low Power Amateur Radio Discussion" <qrp-l at lehigh.edu>
Subject: [126222] FETs and building circuits
Message-ID: <015f01c1f526$ac599940$a3476ad8 at default>
MIME-Version: 1.0
Content-Type: text/plain;
        charset="iso-8859-1"
Content-Transfer-Encoding: 7bit

Hi Everyone, the recent FET thread has been great for
getting me into more building. Doing some searching to
find out different ways and means to use FETs in the QRP
projects has lead me to the following website. All I can say
is WoW, these folks are doing some serious transmitting with
FETs. Now, before you yell at me, just remember that they
are using modules composed of 4 FET units and then
combining them into serious high power Ham radio. Just
using one FET in the QRP projects with the Fairchild FQA11N90
which in small quantities cost around $2.50 is pretty
QRP to my shack budget.

An interesting comment from the author, "Right up front, I need to
say Don't build one of these if you don't have a good oscilloscope!
You will absolutely need a dual-trace scope to really ensure that
your transmitter is working correctly." That just amplifies what
Paul Harden, NA5N, has been telling us, is to get the circuit
components properly selected.

Take a look at http://www.netway.com/~stevec/ham/classe.htm#200w
there are also some great ideas at monitoring your FET circuits
and keeping them happy.

72 / 73 Walter, AG5P

+++++++++++++++

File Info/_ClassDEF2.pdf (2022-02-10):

t = Ciss x Vgs(th)
Ig

Ig = Ciss x Vgs(th)
t

(A)

(B)

Fig. 13 – Gate voltage vs. Ciss and Drain Current (Id)

400

300

200

100

0
0 | 2 | 4 | 6 | 8 | 10
Gate Voltage, Vgs

4A

3A

2A

1A

0A

Gate Capacitance,Ciss, pF

Drain Current, A

Cgs

Id

s: 20nS/
ch1 2v/
f: 10.103
mhz

ch2 2v/
f: 10.103
mhz
Trig: ch1
Dv: 4.1v
Tek
Fig. 14 – Gate Input Waveforms

MOSFET Capacitances

Figure 10 is a graphical representation of the capacitances in a switching MOSFET. An understanding of these capacitances is important for properly driving a class D/E/F PA. Figure 11 shows the nominal values of these

Part 2 is for those with a desire to design and build Class D/E/F amplifiers. The following information, of a more technical nature than Part 1, may be found to be useful for understanding the gate input requirements and some driver circuits.

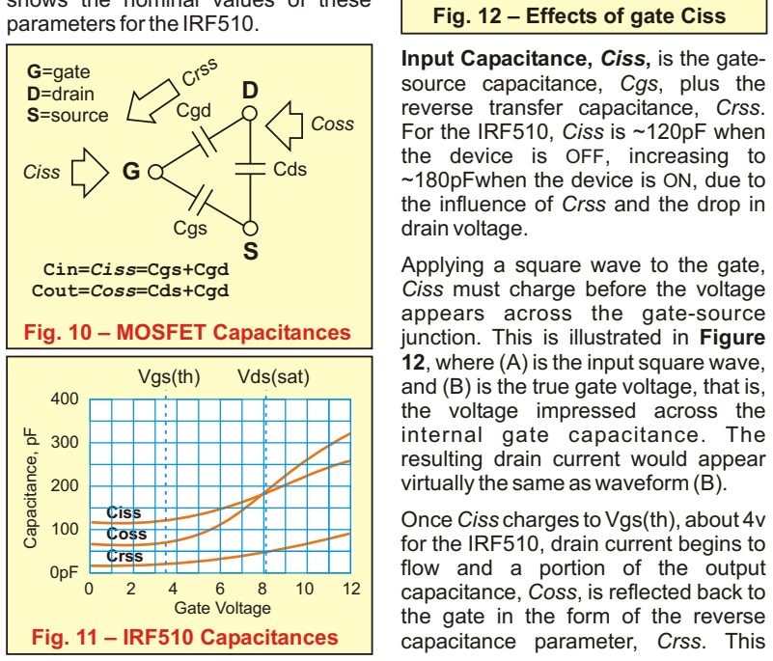
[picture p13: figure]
Fig. 12 – Effects of gate Ciss; Fig. 11 – IRF510 Capacitances; Vgs(th); Vds(sat); Gate Voltage; Capacitance, pF; Coss Crss; Ciss; Fig. 10 – MOSFET Capacitances; Cgd; Cds; rss C; Coss; Cgs; Cin=Ciss=Cgs+Cgd Cout=Coss=Cds+Cgd; G=gate D=drain S=source; parameters for the IRF510.; Input Capacitance, Ciss, is the gate- source capacitance, Cgs, plus the reverse transfer capacitance, Crss. For the IRF510, Ciss is ~120pF when the device is OFF, increasing to ~180pFwhen the device is ON, due to the influence of Crss and the drop in drain voltage.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

and (B) is the true gate voltage, that is,

(and other factors) causes a sudden increase in the gate capacitance at Vgs(th). This is illustrated in Figure 13, with Vgs(th) at 4.0v. The graph is derived from the data sheets, application notes, and measurements I have made on the IRF510.

This rather complex input capacitance graph is not shown in Fig. 11, as most data sheets show only the average capacitance over the gate or drain voltage range, not the aberration that occurs when drain current first begins to flow. This is important to realize, as it alters the actual gate voltage waveform one will observe on an oscilloscope when driving with a square wave.

pure square wave at 10.103 MHz on a 30M transmitter. The bottom trace (Ch.2) is the gate waveform. The gate is biased at 3vdc, such that the TTL square wave drives the gate from about 3v, below Vgs(th), to a little more than 8v for saturation. When the square wave goes from LO to HI, the gate voltage immediate rises to 4.2v, where it hesitates – a visual indication of the actual gate threshold voltage, Vgs(th) for this device. This is the point where drain current begins to flow. The slower slope between Vgs(th) and 8v is due to the increased Ciss above Vgs(th) on Fig. 11. This is also the area of maximum gain of the device. The desired flattening out of the gate drive at 8v indicates the mosfet is in saturation, although this is confirmed by monitoring the drain voltage, as discussed later.

When the gate drive goes from HI to LO, gate voltage returns to the 3v bias level rather sluggishly, due to Ciss discharging. Note that at Vgs(th), the falling waveform again changes it's slope – due to Ciss being altered by the gate junction storage charge effect when gate voltage falls below Vgs(th).

Gate Driver Considerations

Of importance in class D/E/F is the time to reach Vgs(th), the gate threshold voltage, after application of the gate drive going HI. This is described by:

Solving for gate current, Ig:

The above equation indicates that the higher the gate current, provided by the driver stage, the faster Ciss will charge, and the higher the efficiency of the PA.

For class D/E/F, the point of the square wave drive is to get through the linear region as soon as possible. This

Figure 14 is an oscilloscope display showing the waveforms one can expect. The gate waveform serves as a great diagnostic tool in evaluating your class D/E/F transmitter.

I drive the mosfet with a low-Z emitter follower. The top trace (Ch.1) shows the input to the emitter follower, a fairly

# MOSFET "Switched Mode" Amplifiers

### by Paul Harden, NA5N

### (Or, Mosfets for the Obsessive Compulsive)

## The Handiman's Guide to

## Part 2 Gate Input & Drive Requirements

Rd =

= | = 120W

-t
Ciss Ln(1-5v/4v)

-20nS
120pF(-1.38)
Rd = | -t CissLn(1-V2/V1)

100nS
(10 MHz)

h = 90º
= 25nS

h=45º
=12nS

h=90º

(A)

(B)

(C)

Fig. 15
Driver Timing

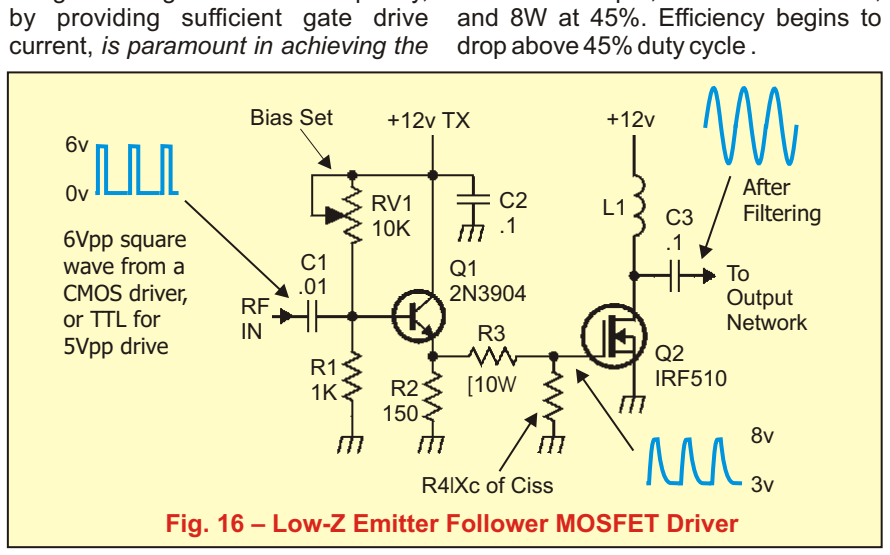
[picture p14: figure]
6Vpp square wave from a CMOS driver, or TTL for 5Vpp drive; R4lXc of Ciss; After Filtering; To Output Network; Q2 IRF510; Bias Set; by providing sufficient gate drive current, is paramount in achieving the; and 8W at 45%. Efficiency begins to drop above 45% duty cycle .

Fig. 16 – Low-Z Emitter Follower MOSFET Driver

means Ciss should be
charged as quickly as
possible.

I recommend striving for
15–20nS. See Figure 15.
This is also consistent with the ~16nS rise time, tr, of the IRF510. "Tr" is
theoretically the fastest
Ciss can be charged.

The figure shows the input gate drive (A) being a 25% duty cycle, or 90º of the RF cycle. At 10.1 MHz, the
gate drive "pulse" would be about 25nS, and to charge
Ciss two times faster would
indicate 12nS, as shown in
(B). From the previous equation, this would indicate a gate current of 50mA is required. This is a bit high for QRP!

I have found a driving current of 25-30mA to be a nice compromise to charge Ciss sufficiently fast for high efficiency. Referring to Fig. 15 (B), if the gate waveform does not flatten out at the 8v level (looks more like a sine wave), the driver is not providing sufficient current to the gate. Driving the gate voltage to saturation quickly,

high efficiency of class
D/E/F. The 25mA of drive
current will save 200mA or more of PA current at 5W
QRP. Observing the o-scope drive waveform in
Fig. 14, note that Ciss
charges in 18-20nS at 10.1 MHz This 30M transmitter
has an overall efficiency of 82%, which includes the
40mA of key-down current
due to the TX mixer,
comparator and emitter
follower driver providing the gate current. This same 18-20nS Ciss charge time will cause a lower efficiency on 20M, as it's approaching
the period of the RF. At 40/80M, this 18-20nS rise time will produce higher efficiencies, since it is a smaller percentage of the RF cycle at lower frequencies..

Also note that the input gate square wave in Fig. 14 is about a 30% duty cycle – 30% ON and 70% OFF. The output power from the class D/E/F PA is determined by the duty cycle. With the IRF510, a 15% duty cycle produces about 1W output; about 5W at 30%,

25mA Emitter Follower Driver

The square wave drive can be developed by some type of CMOS or TTL gate. These alone do not have the current sinking capabilities needed to properly drive the IRF510. Some type of current booster, plus the ability to shift the dc level of the input square wave is required. The emitter follower circuit in Figure 16 is one approach. This works best if you provide a 6V square wave to Q1, such as from a 6–8v CMOS gate, rather than 5V TTL. This is due to the 0.7v drop in the emitter follower, leaving only about 4V from a TTL drive. This may not drive the IRF510 into saturation.

The input square wave is dc shifted by C1 (dc blocking) and the RV1–R1 bias network. Adjust RV1, by monitoring the gate on an oscilloscope, as follows: when the input square wave is LO, the voltage on Q2 gate should be about 3v; when the input goes to +6v HI, the gate voltage should be between 8–9v, depending upon the loading to the circuit. This 3–8v output is developed across R2 and R4. The 3v level is to ensure the IRF510 is OFF, <Vgs(th), and 8v for saturated ON.

Q1 is powered from the +12v TX term to shut down the driver in receive, in the event RV1 is misadjusted to cause mosfet drain current to flow when the mosfet should be OFF.

R3 is 3.9–10W to de-Q the gate and prevent VHF oscillations. The value is not critical. R4 is a resistive load to both the Q1 emitter follower and Q2 gate. The value should be about the Xc of the mosfet Ciss, ~120–180pF, or a few hundred ohms, depending upon the transmit frequency. Initially, you can make R4 a trim pot and adjust for the best possible square wave (Fig. 14) to match to the Ciss of the IRF510. This value will vary from device-to-device.

If the rise time is slower than 25-30nS, then more gate current is needed by decreasing the value of R2. In this example, if a 3v-to-8v signal is formed across R2, then the output drive current would be about 33mA on the drive peaks. (I=5V/150W). Ohms law is thus used to determine R2 for the drive current desired.

In the technical literature, the following equation is used to calculate the driver resistance, Rd, needed (R2 in Fig. 16):

Where, t is the desired rise time of the gate signal (usually 15-20nS), V1 is Vg at saturation, V2 is the peak-to-peak gate voltage, or V1 minus Vgs(on), and Ln is the natural logarithm. For the driver in Fig. 16:

Keep in mind, this value of Rd is based on the ideal current to charge Ciss, about 50mA. Again, I have found 25-30mA to be sufficient. This exercise does show that using Ohms Law for R2 is close enough (and a lot easier!).

The NA5N Mosfet Driver

Another driver scheme developed for my class D/E transmitters is shown in Figure 17. It is similar in some regards to the emitter follower driver in Fig. 16.

The low-level RF output from the TX mixer is applied to a high speed comparator, which converts the RF sinewave into a square wave. The operation of the TX mixer and comparator is beyond the scope of this part of the article, but will be presented in a class D & E transmitter construction project in Part 3. Suffice it to say that the duty cycle of the square wave is variable from about 15–45%. The

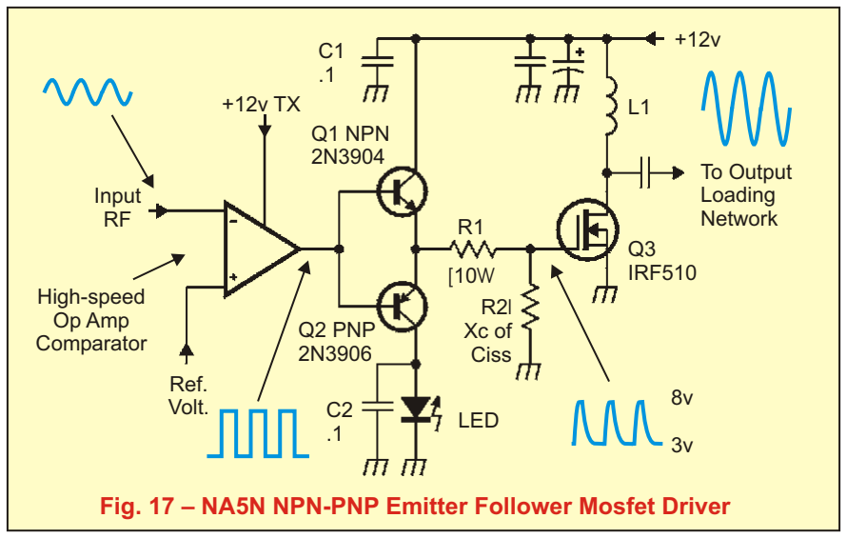
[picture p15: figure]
Q3 IRF510; To Output Loading Network; LED; R2l Xc of Ciss; Input RF; Q1 NPN 2N3904; Q2 PNP 2N3906; High-speed Op Amp Comparator; Ref. Volt.

Fig. 17 – NA5N NPN-PNP Emitter Follower Mosfet Driver

Fig. 18 – Gate/Drain Waveform

s: 20nS/
ch1 2v/
f: 10.112
mhz

ch2 5v/
f: 10.112
mhz
Trig: ch1
Dv: 3.8v
Tek

11-18-2002

comparator is powered from +12v TX, so that during receive, the output is 0v, disabling the IRF510 drive circuitry.

On transmit, the comparator output is an 8Vpp square wave at the RF frequency, such that the dc output levels are about +1v LO to +9v HI.

This emitter follower is an NPN-PNP pair, commonly called a "totem pole" configuration. Since the base voltage is an 8v square wave, the transistors are driven nearly into saturation and cutoff, acting as switches. When the comparator output goes from LO to +9v HI, both the NPN and PNP are turned on. Q1 emitter voltage is the +9v base voltage, minus the 0.7v junction drop. This 8.3 volts is applied to the emitter of Q2, allowing it to be forward biased as well. The 8.3v is also the PA gate drive. R1+R2||Xc is the output load to Q1 and the input impedance to the IRF510, such that the impedance is self matching. This yields 25–30mA of gate current drive from Q1. About 8mA passes through Q2, illuminating the LED.

When the square wave goes to +1v LO, Q1 and Q2 are barely forward biased and conducts ~8mA due to the LED. This causes a 2v drop across the LED, and ~1v across Q2, leaving +3v at the Q1-Q2 emitters – and the mosfet gate – turning off the IRF510.

Even though there is only 2.5v drive to the IRF510 gate, the +8v previously on the gate Ciss is now discharging. This decaying gate voltage also appears on the Q1-Q2 emitters. The low Q2 emitter-collector resistance, which is in parallel to R2, gives Ciss a lower resistance to discharge into. When Ciss is discharged, Q2 turns off. Thus, the purpose of Q2 is to place a low-Z load across the IRF510 gate to quickly discharge Ciss when the mosfet turns off.

For class D/E/F efficiency, the drain current must be zero before the next square wave LO to HI transition occurs.

Figure 18 is an oscilloscope display of this circuit driving a class E transmitter. The top trace is the gate voltage at 2v/div. Vgs(th) of this particular device is 3.8v, shown by the dotted line marker on the oscilloscope. Gate voltage rises fairly quickly to saturate at 8v. When

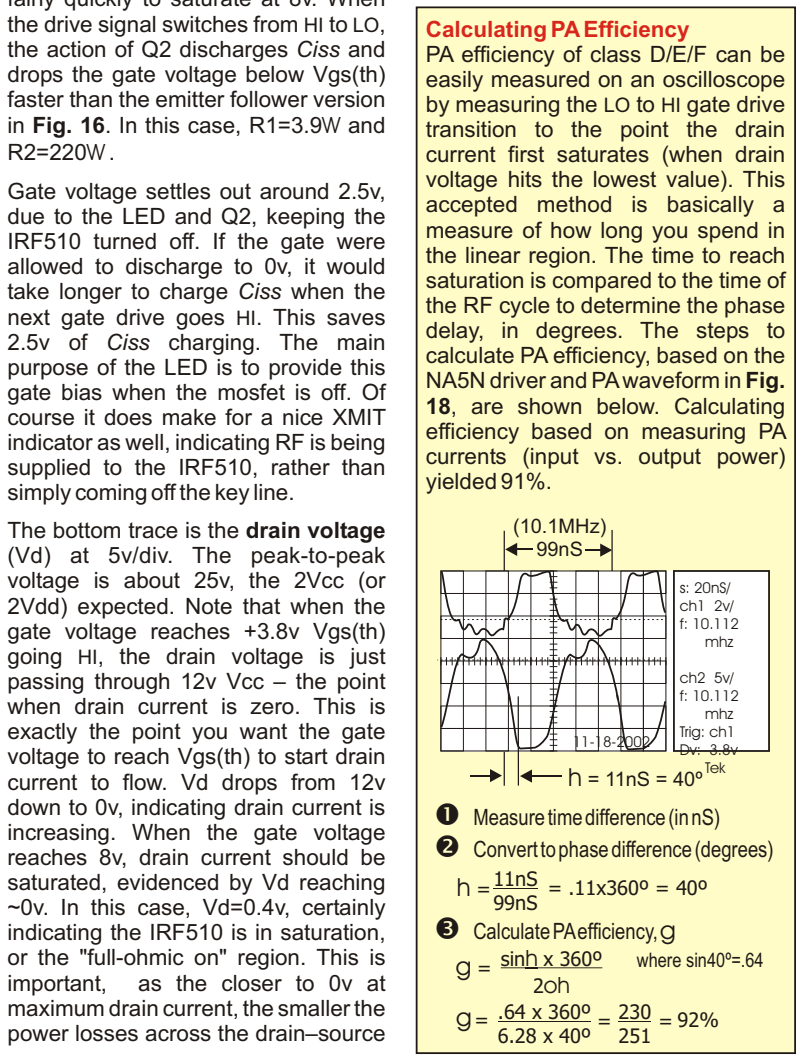
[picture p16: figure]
the action of Q2 discharges Ciss and drops the gate voltage below Vgs(th); in Fig. 16. In this case, R1=3.9W and R2=220W .; Gate voltage settles out around 2.5v, due to the LED and Q2, keeping the IRF510 turned off. If the gate were allowed to discharge to 0v, it would take longer to charge Ciss when the next gate drive goes HI. This saves 2.5v of Ciss charging. The main purpose of the LED is to provide this gate bias when the mosfet is off. Of course it does make for a nice XMIT; supplied to the IRF510, rather than simply coming off the key line.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

the drive signal switches from HI to LO,

faster than the emitter follower version

indicator as well, indicating RF is being junction. The lower the loss, the higher the efficiency. The drain current is also building up the current field in inductor L1 at this time. If drain voltage does not reach <1v, the mosfet is not in saturation.

When the gate voltage begins it's HI to LO transition, to turn OFF the mosfet,

2
Ps = Coss(2Veff) x 2fo =

Veff = VDD–Vsat = 12v–0.5v = 11.5v

=120pF(2*11.5)²
x 2(14MHz) = 1.78W

=

Po
Po+Ps

5W
5W+1.78W = | = 74%

Veff = 18v–0.5v = 17.5v

η =

5W
5W+4.1W

Ps = 120pF(2*17.5)² x2(14MHz) = 4.1W

= 55%

Veff = 12v–0.5v = 11.5v

=

5W
5W+.23W

Ps = 120pF(2*11.5)² x2(1.8MHz) = .23W

= 96% !!!

ing results, as the switching power | meet the above requirements are only
losses double as you double the | available in surface mount packages,
operating frequency. | such as SOT-23's with Id(max) around
1.5–2A. I have built a class D and E PA
A few loose ends ... | with these devices with good success,
IRF510 vs. IRL520 | and surprisingly, the high efficiency
causes little heating of these very The IRL520 is a logic family mosfet, | small packages. However, operating meaning it is designed to saturate with | them Class C causes excessive only 5V (TTL logic HI) on the gate. It | heating above about 2W. There is just would therefore seem the IRL520 | very little room for error with a SOT-23 would be ideal for a class D/E/F PA for | due to the low power dissipation of QRP, since it can be turned on with | such small physical packages. only a 2v swing on the gate. However,
the input capacitance, Ciss, for the | | | | | | | | | | | Other available literature
logic drive devices is very high – in the | There is plenty of available information order of 300-400pF. This is tolerable | on Class D/E/F transmitters on various for their intended purposes in 50-100 | websites, engineering magazine KHz switching power supplies, but | articles and the application notes in virtually impossible to drive at HF | National and Motorola data books. frequencies. I have built some fairly | However, this information needs to be successful Class C PAs with IRL520's, | used with caution for QRP, as most are but efficiencies at Class D/E/F never | based on RF type switching mosfets, much more than 50%. Theoretically, | deal with power ranges in the hun- one can drive the gate with a parallel | dreds of watts, push-pull circuits, or inductance to cancel out this huge | frequencies below HF, such as for AM
capacitance through resonance, but I | broadcasting or ultrasonic use. Still, have not yet tried this. There are some | these articles are worth further study SMC SOT-23 logic mosfets with a | for those wishing to learn more, lower Ciss worth experimenting with. | keeping the application of the article in
Other switching MOSFETs | mind.
Just look through the Mouser or Digi- | Interpretting the IRF510 Data Sheet
Key catalog and you will see listings for | The data sheet for the International- legions of cheap, switching mosfets. | Rectifier IRF510 is in Appendix B. Many can be used in lieu of the | This is extracted from their complete IRF510. In order to use them for Class | data sheet. D/E/F, you need to know primarily the
Vgs(th), Vg(sat), and output capaci- | | Maximum Ratings. Continuous drain
tance, Coss or Cds. Maximum drain | | current is important, as this is about the
current is also important. For QRP | | drain current for the period of time the
power levels, you want a device with a | | IRF510 is in saturation. This should
Id(max) of 1-2A for smooth power | | stress why controlling output power
control with a 50% duty cycle, since | | with a small duty cycle is important.
you are forcing maximum Id for some | | Maximum gate-to-source voltage is
period of time. The IRF510 Id(max) is | | !20v, which will easily handle the +10v
about 4A. Such a high Id(max) actually | | required for saturation.
makes the IRF510 a bit difficult to | Electrical Characteristics. RDS(on) control in the 5W or less range. | is the "on-resistance," which only
Surface Mount MOSFET's | | occurs when fully saturated. Note the
Test Conditions define the saturated Some of the switching mosfets that

Ps is the switching loss in watts):

In some of the amateur literature, the recommendation is sometimes given to raise the mosfet drain voltage for higher efficiency. Let's see if this is true.

drain voltage begins to rise, indicating drain current is turning off as desired. Gate voltage drops from +8v to +3.8v Vgs(th) faster than the single emitter follower waveform in Fig. 16, due to the loading effect of Q2. Drain voltage rises above 12v Vdd as the current stored in L1 now dumps into the output network when drain current stops.

In class E, L1 is also part of the output tuned circuit, resonant at the transmit frequency by the shunt capacitor in conjunction with the internal Coss. See "Cv" in Fig. 6, Part 1. When the current stored in L1 is depleted, drain voltage will begin to decrease. However, in class E, the energy stored in the capacitor parallel to L1 will provide voltage when the current in L1 is depleted, causing the familiar "fly-wheel" effect of the resonant circuit. In Fig. 18, the hesitation in drain voltage at 20v is when L1 runs out of current, and the voltage peak to 25v is the voltage being supplied by the shunt capacitor, which has been charged to 2Vdd. Two or three peaks may be seen at the 25v level, depending upon the harmonic power present. With this waveform, the transmitter had a power range of 1W to 9W (by varying the duty cycle from 15% to 45%) with an overall efficiency of 85% and a PA efficiency of 92%.

, is based
on the switching power, Ps, lost across Coss. The following math only serves to make two important points below.

At VDD=12v, for a 20M 5W transmitter, with Cs=120pF and Vsat=0.5v (where

Class D Drain Output Efficiency

The output capacitance, Coss, lowers efficiency, since it must be charged to ~2VDD by the mosfet. The equations below show how efficiency,

At VDD=18v, to produce 5W output power:

Increasing VDD to 18v does produce 5W with less drain current. However, charging Coss to 36v (2VDD) greatly increases the switching power loss, lowering efficiency from 74 to 55%. This should dispell the rumor that increased VDD lowers efficiency – and that the +12v customarily used by
homebrewers is actually quite ideal for switching mosfet QRP PAs.

The second point with the above equations is how the switching losses are frequency dependent, due to the term "2fo." The lower the frequency, the lower the losses, and hence higher efficiency. Therefore, a Class D/E/F PA will be much more efficient on 80M than 20M. This is why most Class E circuits on the internet are only for 160M or 80M, as even a sloppy job of designing the circuit and using a sinewave drive

will still yield high efficiency. Re-calculating the 20M 12v QRP example to 160M yields an astounding 96%. This is also why those scaling these amplifiers for 20M have had disappoint-

state with VGS=10v. When in the | current flows, producing more heat,
linear region, RDS is the standard | then more current, until the device 2
equation for R
L | destroys itself by thermal runaway. = Vdd /2Po.
Again, a mosfet protects itself from Vgs(th) is the gate voltage where | thermal runaway. This explains why drain current begins to flow. Note | your class C IRF510 PA drops in the huge range - typical of mosfets. | output power as the device gets Most devices will be about 3.5-4v. | hot. LD is the internal inductance that
adds to the external inductance on | Fig. 4 is the transfer characteristics
of the IRF510. This shows how the drain. In class E, where the
drain inductance forms a tuned | much drain current flows vs. the
circuit, the value of L
D | gate voltage. Note that the graph is sufficiently
begins at 4v, as less than that, the low to not alter calculations. Ciss
and Coss | mosfet is in "cut off." Also note the are the input and output
capacitances. These are very | drain current is less at 175ºC. This
shows how device saturation important, especially for class
D/E/F | occurs around Vgs=8v, where little . Note the test conditions are
further increase in drain current for Vgs=0v, that is, with no drain
current flowing. With drain current, | occurs with increasing Vgs. Below
Vds will drop from +12v to 0v (at | Vgs=8v is the linear region,
saturation) and these values | although it is not very linear (more
change, as shown in Fig. 3 | "curved" in shape). The transfer on the
data sheet.
T | curve is steepest between about 4 iming parameters,
Td(on) | to 5v Vgs. This is the area of , Tr and Td(off) are defined
maximum gain. This shows why in Fig. 6. For class D/E/F, the faster IRF510s have also been used as the better. Theoretically, the fastest
a mosfet can switch is the time of | very high gain RF amplifiers or Tr+Tf+Td(on)+Td(of | mixers, by exploiting a gate voltage f), which
equals 54nS for the IRF510. Tf is | only slightly above Vgs(th).
assumed to be about
Tr if not listed. | Fig. 5 shows the maximum drain The maximum frequency would | current vs. temperature. For class thus be 1/54nS = 18.5MHz. Tr and | C QRP transmitters, device Tf define the typical time to charge | temperature can quickly rise to and discharge Ciss and Coss. | 150ºC on key down, but still in the These times can be increased a bit | safe operating region for 1A of drain by increasing the gate drive | current. Class D/E/F runs consider- current, as discussed in the article, | ably cooler. In fact, a barely warm and raising fmax to some extent. | IRF510 after 30 seconds of
Fig. 1 | keydown is the ultimate proof of the shows drain current (Id) vs
increased efficiency.

Try that with the drain-source voltage (Vds) at
25ºC. This is similar to the transfer | | | | class C and you'll loose your finger-
characteristic curves for a BJT | print! . Fig. 2 is the same, except at a device | In Part 3 of this series will be two temperature of 175ºC. Note that as | construction projects for you to the IRF510 gets hotter, drain | build – a QRP Class D and E
current gets less, protecting itself | transmitter using the IRF510. Both from thermal runaway. This is | can be added to about any QRPp opposite the effect of a BJT, where | transmitter to produce 5W output, the BJT gets hotter, more collector | or for a "roll-your-own" transmitter.

72, Paul Harden, NA5N
na5n@zianet.com
pharden@nrao.edu

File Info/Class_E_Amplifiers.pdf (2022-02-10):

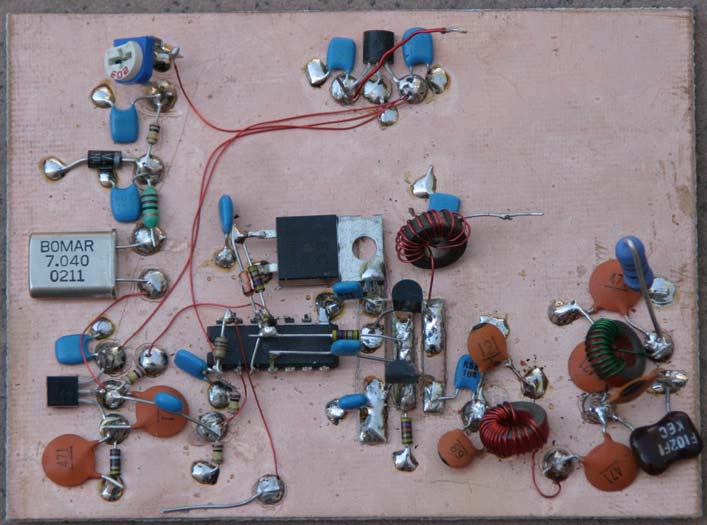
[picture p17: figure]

April-04 | N7VE / Ozarkc Copyright 1994, All rights reserved | on Class E Presentation

# Class E Amplifiers

## Part 1: Class E Basics

## Dan Tayloe, N7VE

## 5w Class E 40m Prototype

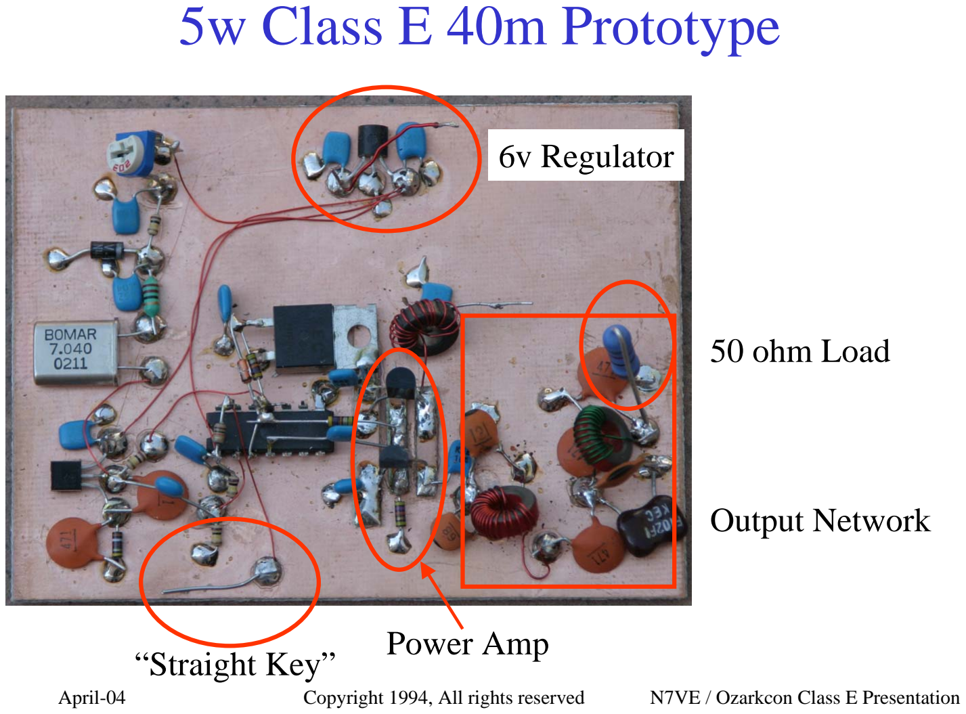
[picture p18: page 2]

April-04 | N7VE / Ozarkc Copyright 1994, All rights reserved | on Class E Presentation

Power Amp

6v Regulator

Output Network

50 ohm Load

“Straight Key”

April-04 | N7VE / Ozarkc Copyright 1994, All rights reserved | on Class E Presentation

# Why Class E?

Class C final, 2w
40 to 45% efficient, ~ 370 to 410 ma*

Class E final, 2w
88% efficient, ~ 190 ma*

Almost 50% less TX current required… Very battery friendly!

* Does not include PA driver. Class E can require very little driver power!

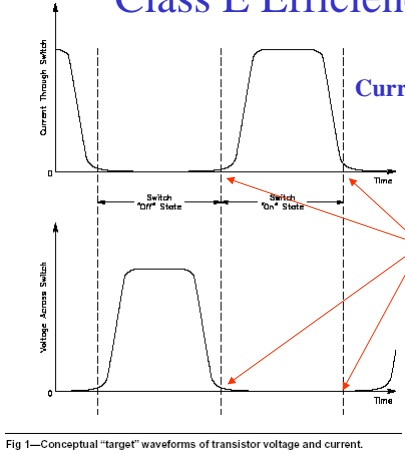
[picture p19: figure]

April-04 | N7VE / Ozarkc Copyright 1994, All rights reserved | on Class E Presentation

# Class E Efficiency Secret

Voltage vs. time

Current vs. time

Taken from QEX Jan/Feb 2001

Switch at low current,
Low voltage points
~Zero power at switch!

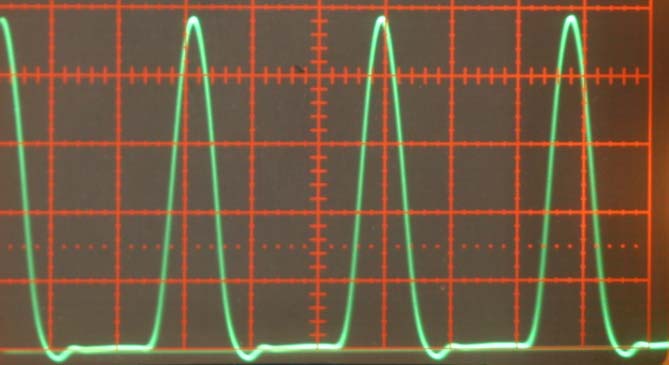
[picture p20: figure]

April-04 | N7VE / Ozarkc Copyright 1994, All rights reserved | on Class E Presentation

# Class E Drain Voltage Waveform

Scale 10v/division
~ 48v at peaks for 5 w, ~40v for 2w
For comparison, Class C devices run only 24v peaks

## Class E Design Spread Sheet, 7 MHz

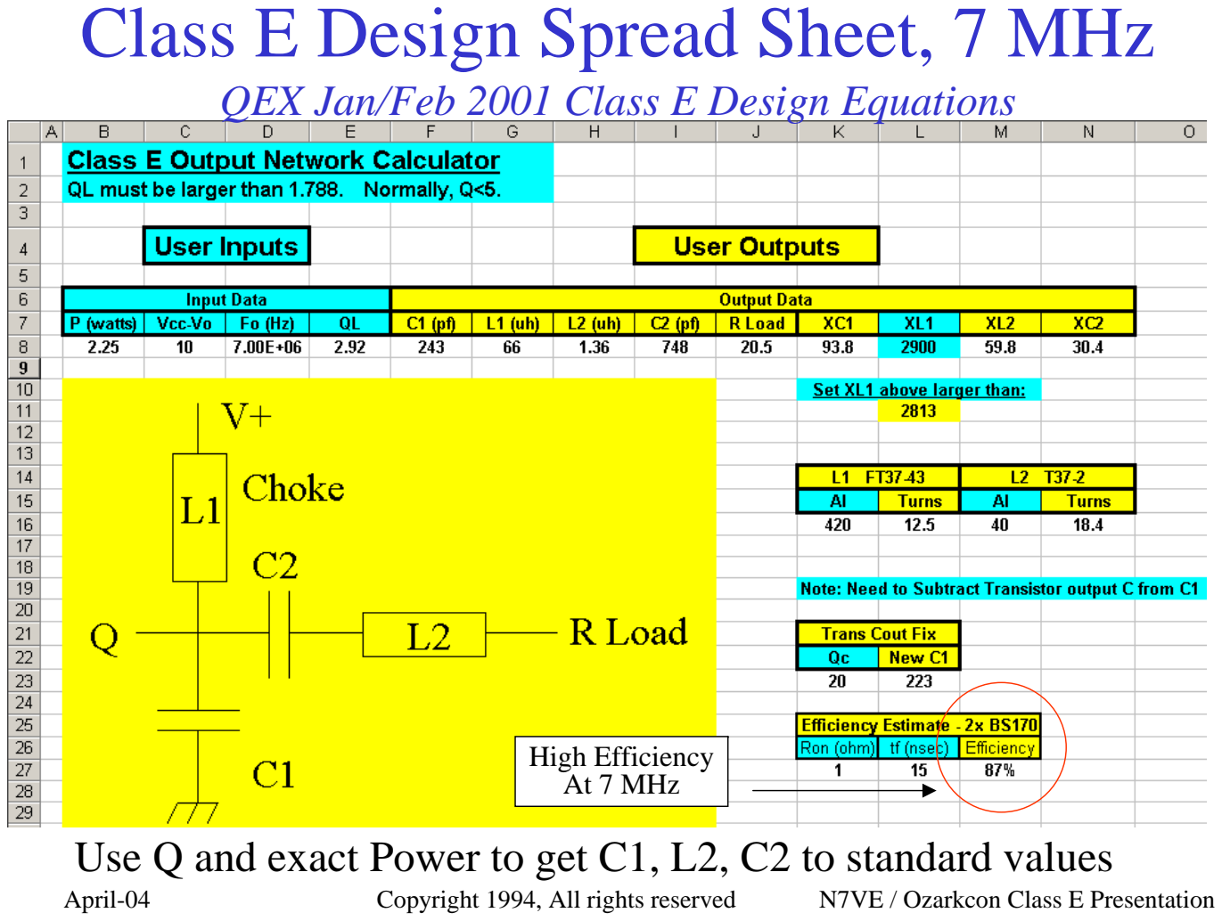
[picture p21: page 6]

April-04 | N7VE / Ozarkc Copyright 1994, All rights reserved | on Class E Presentation

QEX Jan/Feb 2001 Class E Design Equations

High Efficiency
At 7 MHz
Use Q and exact Power to get C1, L2, C2 to standard values

## Class E Design Spread Sheet, 14 MHz

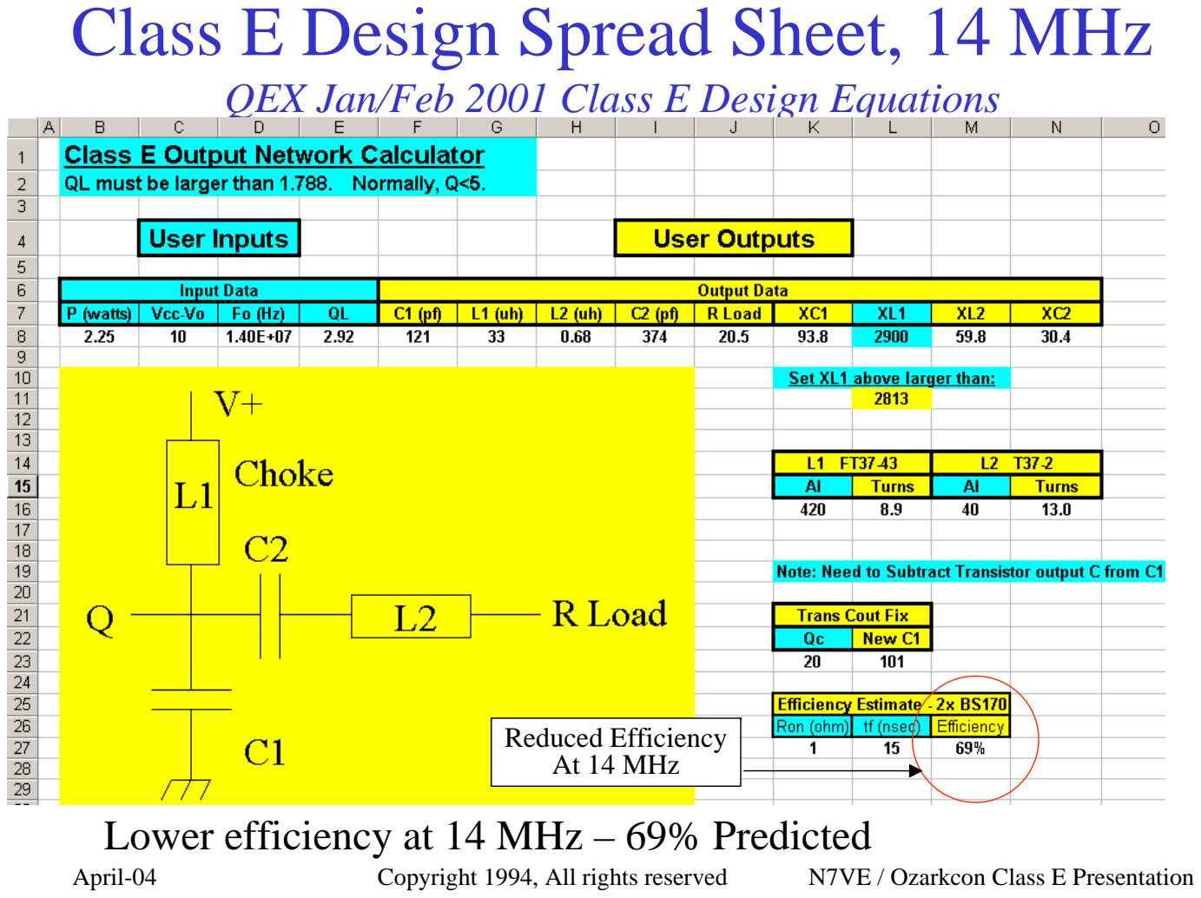
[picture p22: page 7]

April-04 | N7VE / Ozarkc Copyright 1994, All rights reserved | on Class E Presentation

QEX Jan/Feb 2001 Class E Design Equations

Reduced Efficiency
At 14 MHz
Lower efficiency at 14 MHz – 69% Predicted

April-04 | N7VE / Ozarkc Copyright 1994, All rights reserved | on Class E Presentation

# Class E Design Spread Sheet

Excel spread sheet equations…

C1 (pf) = (1e12/(J8*34.2219*D8))*(0.99866 + 0.91424/(E8) -1.03175/(E8*E8)) + 0.6/(2*2*3.14*3.14*D8*D8*G8/1000000)

C2 (pf) = (1e12/(J8*2*3.14*D8))*(1/(E8-0.104823)) *(1.00121 + 1.01468/(E8 - 1.7879)) -0.2/(2*2*3.14*3.14*D8*D8*G8/1000000)

L1 (uH) = 1000000*L8/(2*3.14*D8)

L2 (uH) = 1000000*J8*E8/(2*3.14*D8)

Rload = (C8*C8/B8)*0.576801*(1.001245 - 0.451759/E8 - 0.402444/(E8*E8))

XL1 >= 30*K8

Efficiency = J8/(J8+1.365*K27) -0.01
- (1+ 0.82/E8)* (1+ 0.82/E8)*4*PI()*PI()*D8*D8*L27*L27*1e-18/12

April-04 | N7VE / Ozarkc Copyright 1994, All rights reserved | on Class E Presentation

# Class E Amplifiers

## Part 2: No Tune, Goof Proof Class E Amps

## Dan Tayloe, N7VE

April-04 | N7VE / Ozarkc Copyright 1994, All rights reserved | on Class E Presentation

# Problems with Class E QRP Amps

- “Tuning” required to get good efficiency
- Poor “out of the box” power and efficency
- Typical to “tweak” output network coils for best power/efficiency
- Class E finals fail when presented with low impedance loads
- Low impedance loads cause PA to draw too much current and burn up
- Inexpensive QRP Class E final rated to only 60v (2N7000)
- Typical PA drain voltage operates in the 40 to 50v range w/ 12v supply
- Improper antenna mismatch can raise drain voltage, blow the PA
- 15v supply used with a 12v design could cause problems
- Class E Amps can be unstable into poorly matched loads
- Tends to “take off”
- Can lead to device failure

April-04 | N7VE / Ozarkc Copyright 1994, All rights reserved | on Class E Presentation

# Class E Tuning Problem

- Class E matching network typically presents a reactive load
- I.e., the Class E PA output impedance is not purely resistive
- Reactive characteristic key to Class E efficiency
- QRP Class E networks need loads in the 10 ohm to 50 ohm (5w to 1w) range
- Matching network normally needed to transform to 50 ohm load
- 1 watt 12v final is a design “sweet spot” – no matching needed
- L/C matching networks are typically used to transform driver impedance to 50 ohm load impedance.
- This approach does not work well with a reactive drive source!
- Leads to frequency specific matching network
- Variations in driver network and matching network elements force the need for “tuning” of the matching networks

# No Tune Class E

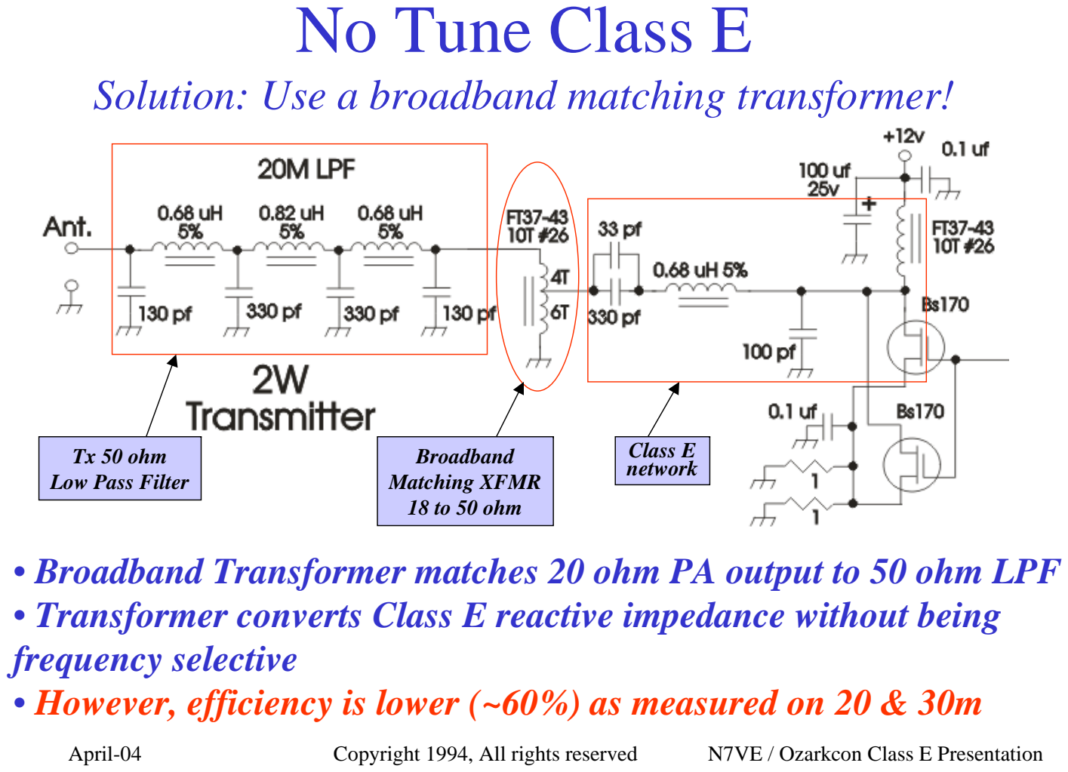
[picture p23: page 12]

April-04 | N7VE / Ozarkc Copyright 1994, All rights reserved | on Class E Presentation

Solution: Use a broadband matching transformer!

- Broadband Transformer matches 20 ohm PA output to 50 ohm LPF
- Transformer converts Class E reactive impedance without being frequency selective
- However, efficiency is lower (~60%) as measured on 20 & 30m

Tx 50 ohm
Low Pass Filter

Broadband
Matching XFMR

### 18 to 50 ohm

Class E
network

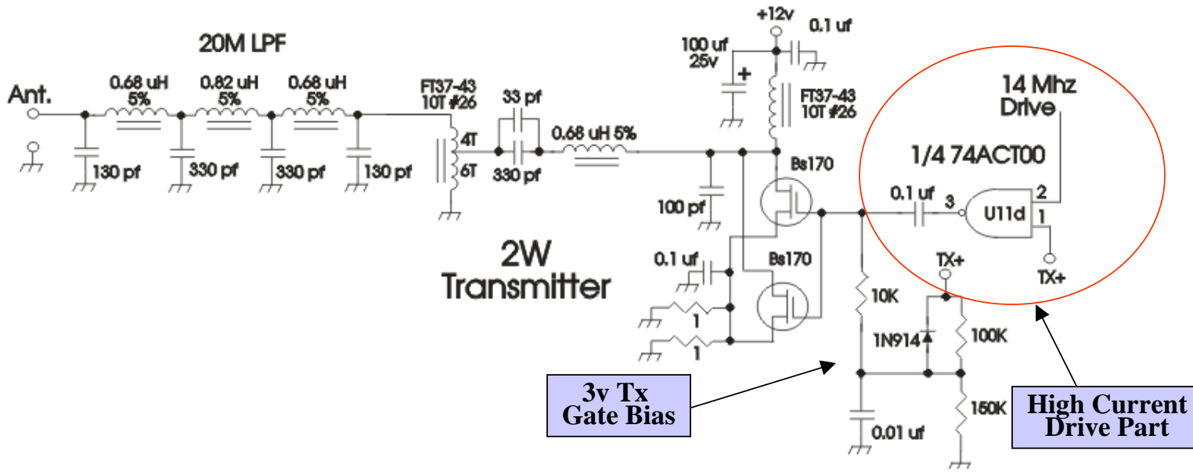
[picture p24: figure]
Gate Bias; High Current Drive Part

April-04 | N7VE / Ozarkc Copyright 1994, All rights reserved | on Class E Presentation

# Class E Load Instability

Solution: Use a lower impedance gate driver!

- AC family has 24 ma of drive vs 8 ma for HC family
- Higher current drive = lower drive source impedance
- 3x lower source impedance reduces tendency to “flight” with mismatched load
- PA gate biased on TX to 3v to help MOSFET turn on harder

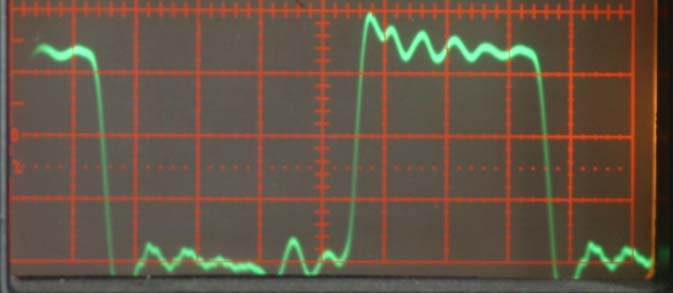
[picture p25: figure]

April-04 | N7VE / Ozarkc Copyright 1994, All rights reserved | on Class E Presentation

# Class E Driver – 74ACT00

Scale: Vertical 2v/div, Horizontal 20 nsec/div 6 to 8v at peaks
Very fast rise+fall times: ~10 nsec total

74ACT00 has 24 ma of drive vs. only

8 ma for
the more common 74HCT00 parts

# Class E Voltage Limitations

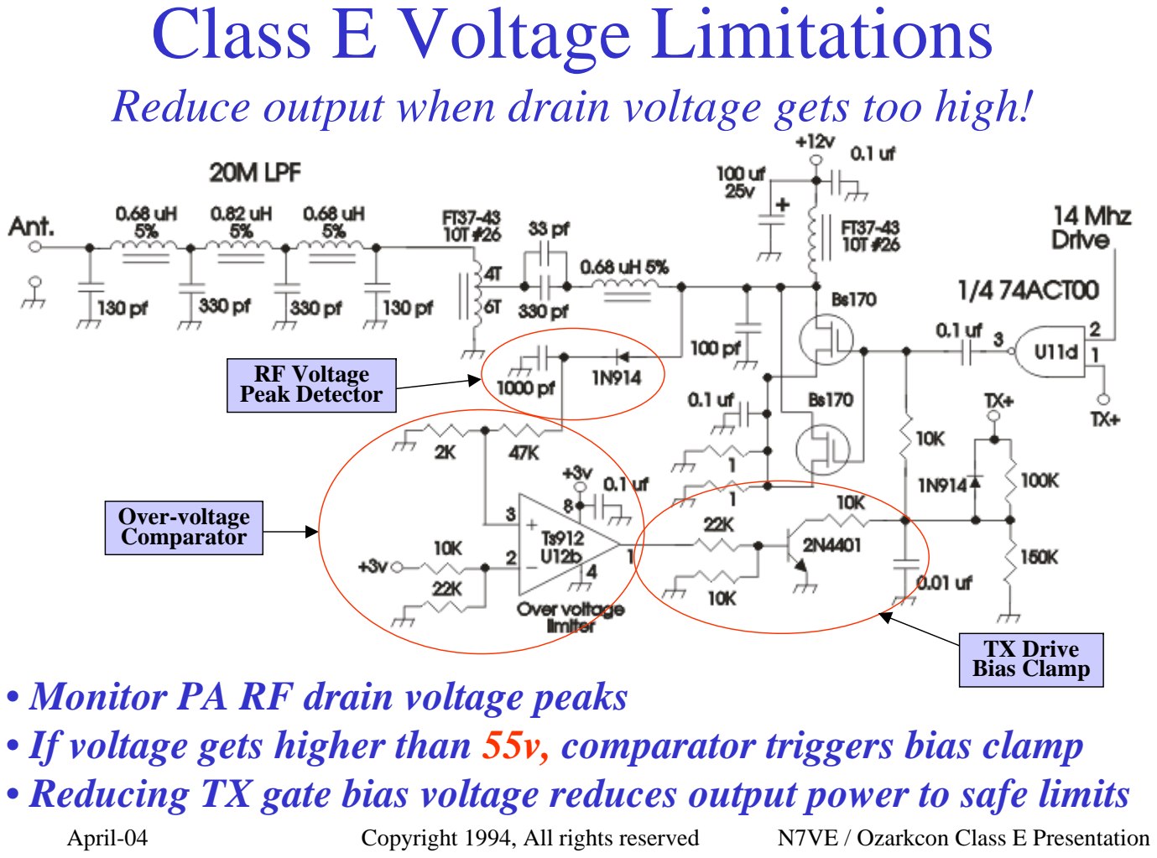
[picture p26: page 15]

April-04 | N7VE / Ozarkc Copyright 1994, All rights reserved | on Class E Presentation

Reduce output when drain voltage gets too high!

- Monitor PA RF drain voltage peaks
- If voltage gets higher than 55v, comparator triggers bias clamp
- Reducing TX gate bias voltage reduces output power to safe limits

Over-voltage Comparator

RF Voltage Peak Detector

TX Drive
Bias Clamp

# Class E Low Load Limitations

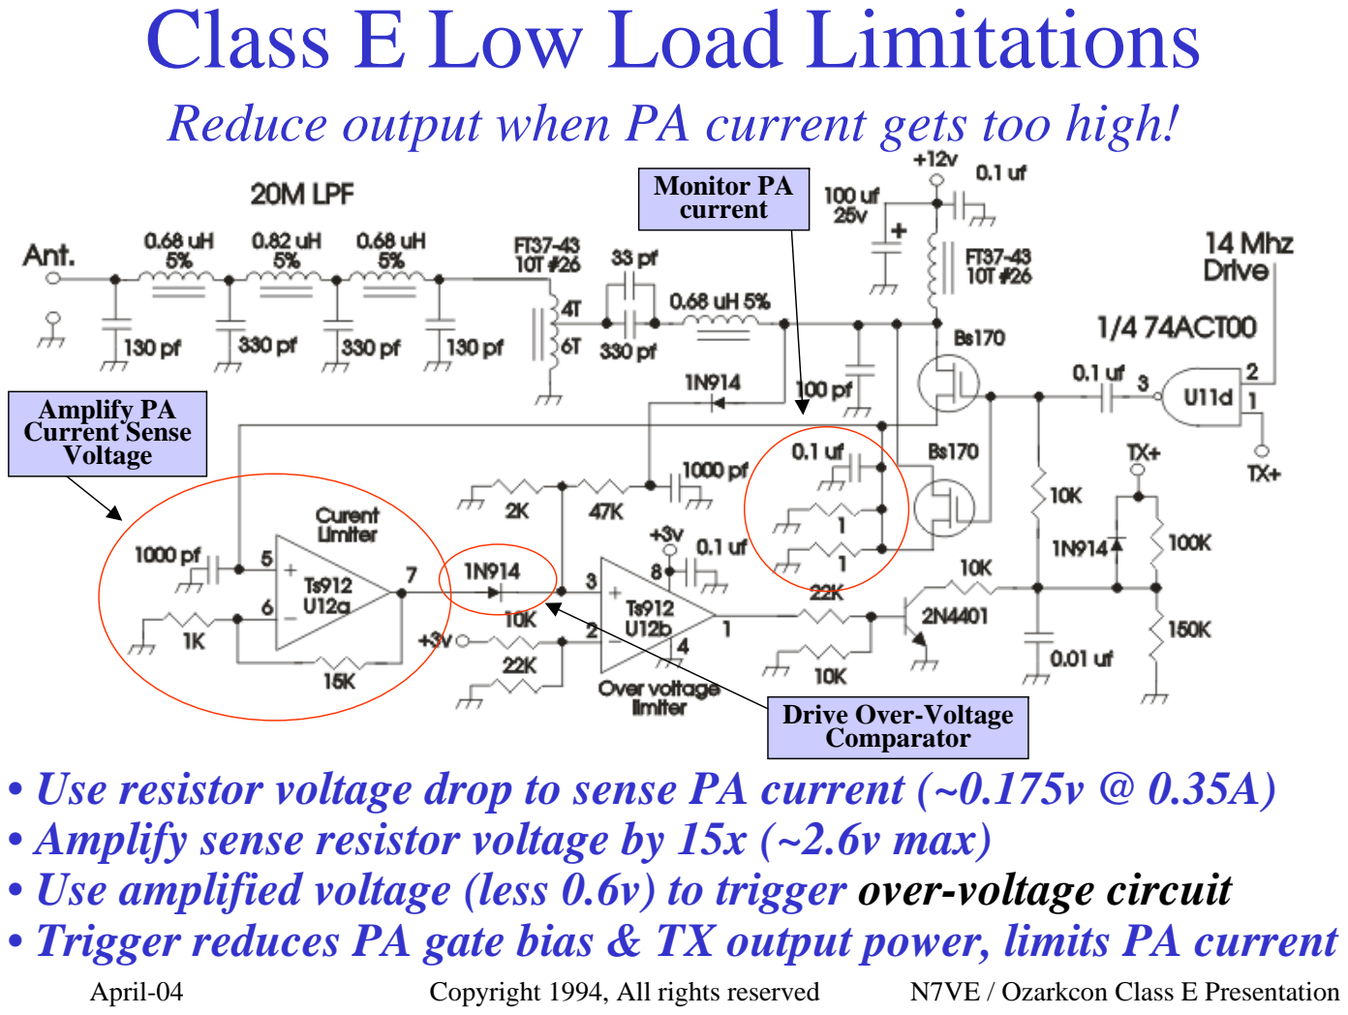
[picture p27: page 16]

April-04 | N7VE / Ozarkc Copyright 1994, All rights reserved | on Class E Presentation

Reduce output when PA current gets too high!

- Use resistor voltage drop to sense PA current (~0.175v @ 0.35A)
- Amplify sense resistor voltage by 15x (~2.6v max)
- Use amplified voltage (less 0.6v) to trigger over-voltage circuit
- Trigger reduces PA gate bias & TX output power, limits PA current

Monitor PA
current

Amplify PA Current Sense
Voltage

Drive Over-Voltage Comparator

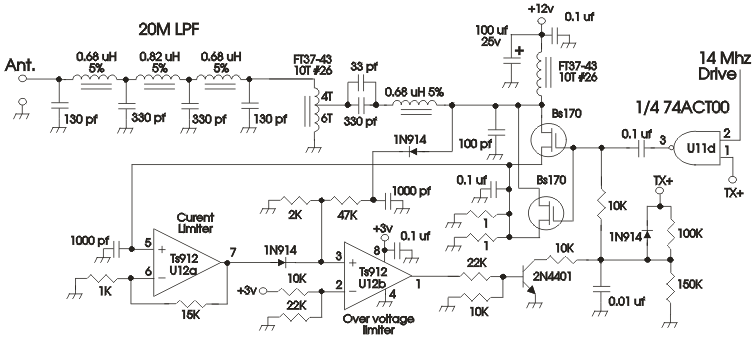
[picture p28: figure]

April-04 | N7VE / Ozarkc Copyright 1994, All rights reserved | on Class E Presentation

## No Tune, Goof Proof, Class E Tx

- High impedance over-voltage protection
- Low impedance over-current protection
- “No Tune” Class E output

April-04 | N7VE / Ozarkc Copyright 1994, All rights reserved | on Class E Presentation

## Current Class E Limitations

- Efficiency of common QRP PA devices (2N7000, BS170) drops off at 14 MHz and above
- ~80 to 90% efficiency at 10 MHz and below
- ~70% efficiency at 14 MHz
- ~60 % efficiency using “no tune” approach shown here
- R/C freq response: Smaller Driver R = Higher Freq response
- Higher PA drive power can be used to get higher freq PA response
- Higher PA drive power hurts overall transmitter power saving
- Higher frequency devices available, but more expensive
- Example: STMicroelectronics PD57006s 900 MHz 5w FET, ~$12

April-04 | N7VE / Ozarkc Copyright 1994, All rights reserved | on Class E Presentation

## Current Class E Limitations, cont

- Class E operates at a fixed power set by Class E output network
- Variable power best done by changing supply voltage
- May be able to reduce power from preset maximum by lowering TX gate drive bias, but at reduced TX efficiency.

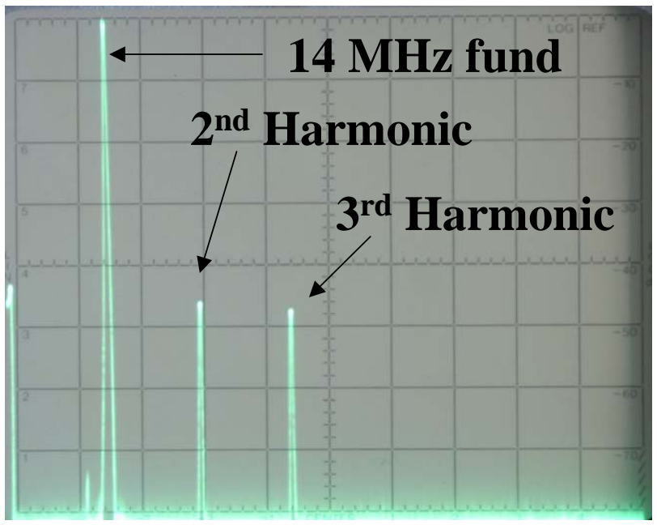
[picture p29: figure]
14 MHz fund 2nd Harmonic; 3rd Harmonic

April-04 | N7VE / Ozarkc Copyright 1994, All rights reserved | on Class E Presentation

# Transmitter Spectrum

Scale 10 db/division – legal limit 30 db down 2nd Harmonic ~45 db down
3rd Harmonic ~47 db down
All other more than 70 db down

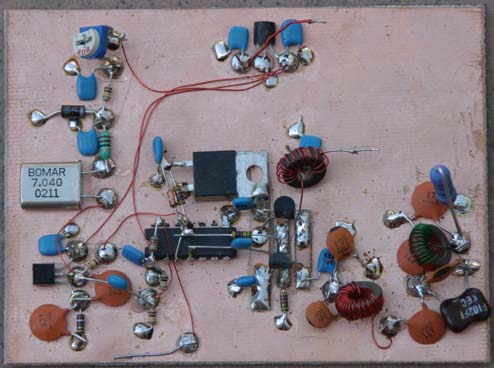
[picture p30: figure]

April-04 | N7VE / Ozarkc Copyright 1994, All rights reserved | on Class E Presentation

# Class E Amplifiers

## Part 3: Good & Bad QRP Class E Devices

Or

## “Bigger is not Better”

## Dan Tayloe, N7VE

April-04 | N7VE / Ozarkc Copyright 1994, All rights reserved | on Class E Presentation

# Why the IRF510 Makes a Good 5w Class C PA

## - IRF510 on/off time 70 nsec, good to 14 MHz - 40 to 45% efficiency typical using broadband, low pass TX output filters - 5w output requires 11.1w input power

– 6.1w of heat produced!
– 33w IRF510 can take the heat
if proper heat sink is used

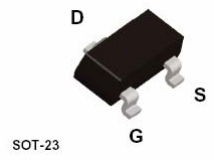
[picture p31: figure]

April-04 | N7VE / Ozarkc Copyright 1994, All rights reserved | on Class E Presentation

# Why the 2N7000 makes a good QRP Class E final

# and the IRF510 does not

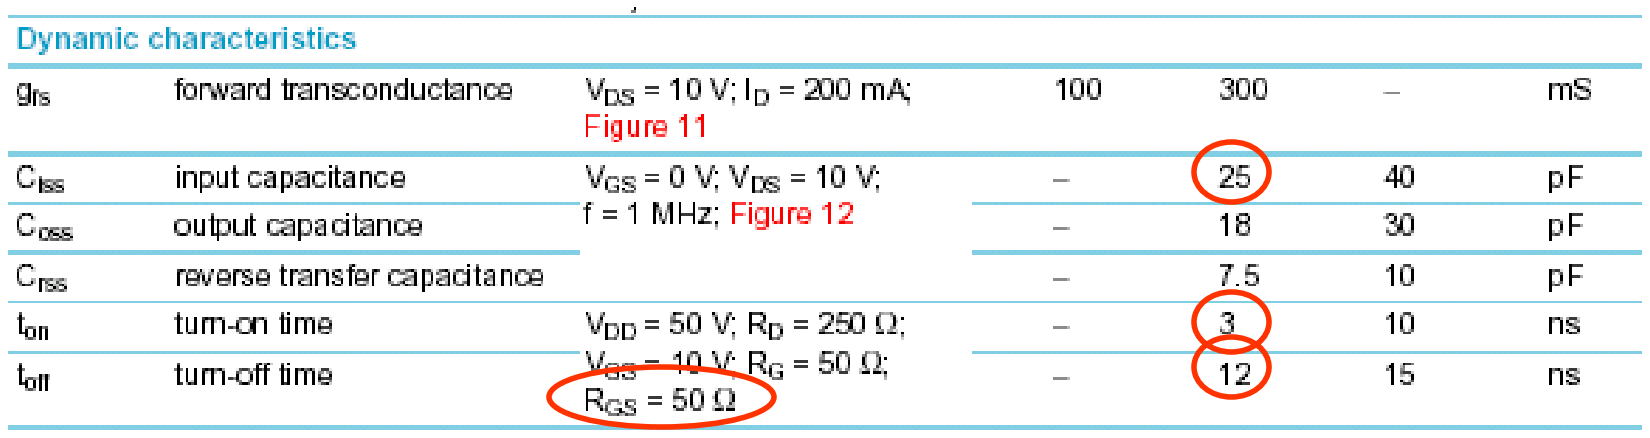
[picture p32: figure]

April-04 | N7VE / Ozarkc Copyright 1994, All rights reserved | on Class E Presentation

# Good FET – 2N7000, 0.3 to 0.6w

Low input C: 25 pf typical – Low input drive drive!
Fast Turn on/off time: 3+12 nsec = 15 nsec

For class E, need On/Off to be 30% of ½ RF cycle (QEX 1/01)
- Gives maximum limit of 10 MHz for full efficiency
- Can be used at 14 MHz at reduced efficiency
- Measured 80-90% at 7 & 10 MHz, 70% at 14 MHz

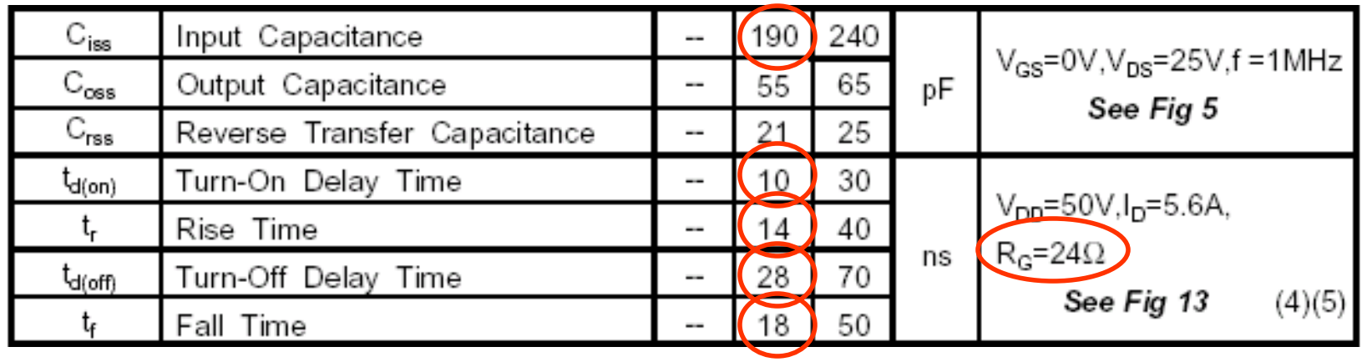
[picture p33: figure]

April-04 | N7VE / Ozarkc Copyright 1994, All rights reserved | on Class E Presentation

# Difficult FET – IRF510, 33w

Higher input C: 190 pf typical – Higher input drive needed!
- Specs use 24 ohm source here vs. 50 ohm source for 2N7000
Slower Turn on/off time: 10+14+28+18 nsec = 70 nsec For class E, need On/Off to be 30% of ½ RF cycle
- Gives maximum limit of 2 MHz for full efficiency
- Can speed up by using a lower impedance drive source.
- Slam it on, slam it off! – more drive power needed. Double driver power hit: High input C & Slow switching time

April-04 | N7VE / Ozarkc Copyright 1994, All rights reserved | on Class E Presentation

## Class E Driver Requirements IRF510 vs. 2N7000

- IRF510, 190 pf input gate C; 2N7000, 25 pf
– Drive power factor of 7.6x
- IRF510, 25 ohm source; 2n7000, 50 ohm source
– Drive power factor of 2x
- IRF510, 70 nsec turn on/off; 2n7000, 15 nsec
– Need 4.67x lower drive impedance to get same speed
- IRF510 requires 5 ohm driver impedance for 15 nsec on/off
Total drive difference: IRF510 needs 71x more drive power than a single 2N7000
~ 0.6w drive for class E IRF511 vs. 17mW for a pair of 2N7000s
IRF510: Good 100w Class E amp, poor 5w amp!

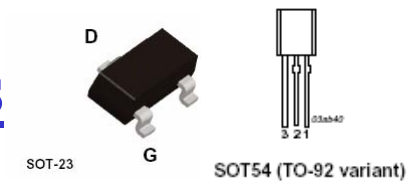
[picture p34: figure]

April-04 | N7VE / Ozarkc Copyright 1994, All rights reserved | on Class E Presentation
- Class E saves ~ 50% on TX DC input power to PA
– Low drive power (17 mW vs. 0.6w) saves additional power
- Class C requires large TO220 PA transistors
- Class E needs only tiny T092/SOT23 300mw/600mw packages
- $0.14 for a new pair of Class E QRP finals!
- Low wasted TX pwr (Heat

)
– For 5w output, 0.5 to 1w heat (class E) vs. 5 to 6w heat! – Conserves battery life (smaller battery?)
– Reduces VFO drift

# Conclusions

April-04 | N7VE / Ozarkc Copyright 1994, All rights reserved | on Class E Presentation

# Class E Summary

## - Class E can give up to 88% efficiency

– But require tuning to get proper power output
- Protection circuitry available for Class E finals
– Protects against antenna open/short/mismatch problems
- “No Tune” Class E works, but ~60% efficiently
- Bigger is not better for Class E finals
– High power MOSFETs (such as the IRF511) require high drive power (71x!), reducing overall rig efficiency.

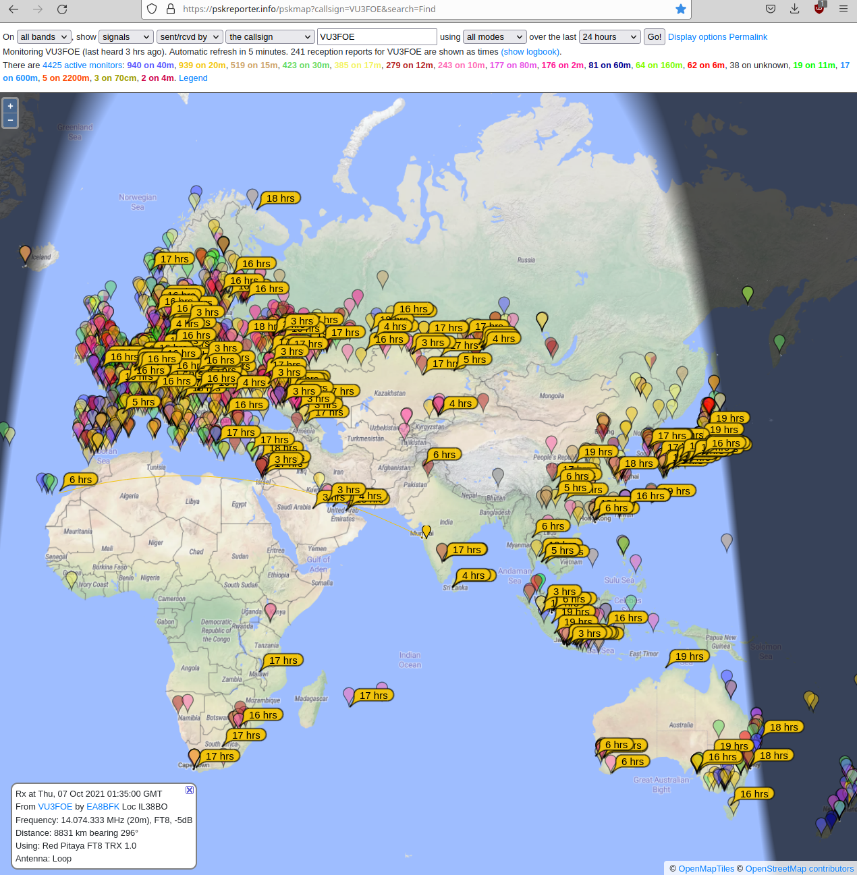
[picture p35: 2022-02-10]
RX-Reports/Screenshot_2021-10-07_13-20-47.png

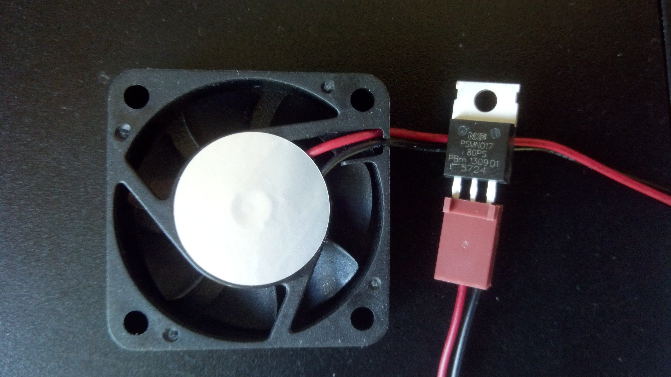
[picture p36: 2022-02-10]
Socketable-Design/Molex 2.54mm pitch connector.jpg

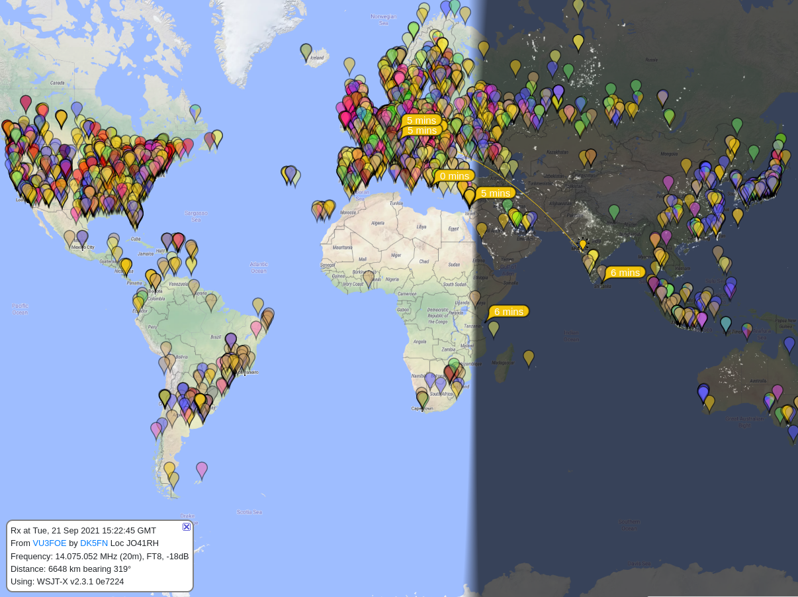
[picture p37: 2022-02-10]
RX-Reports/Screenshot_2021-09-21_20-58-14.png

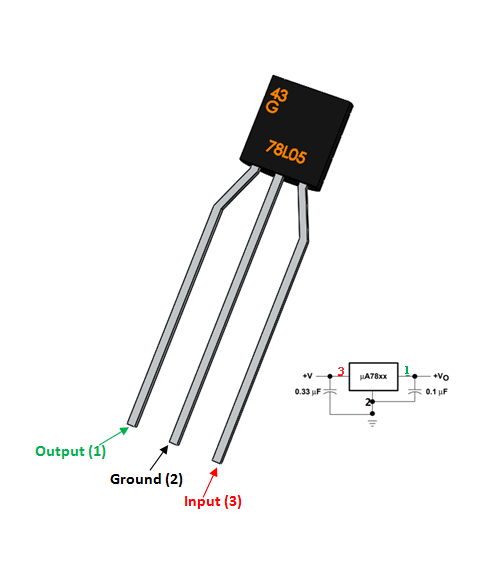
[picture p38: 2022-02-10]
Info/78L05-Pinout.png

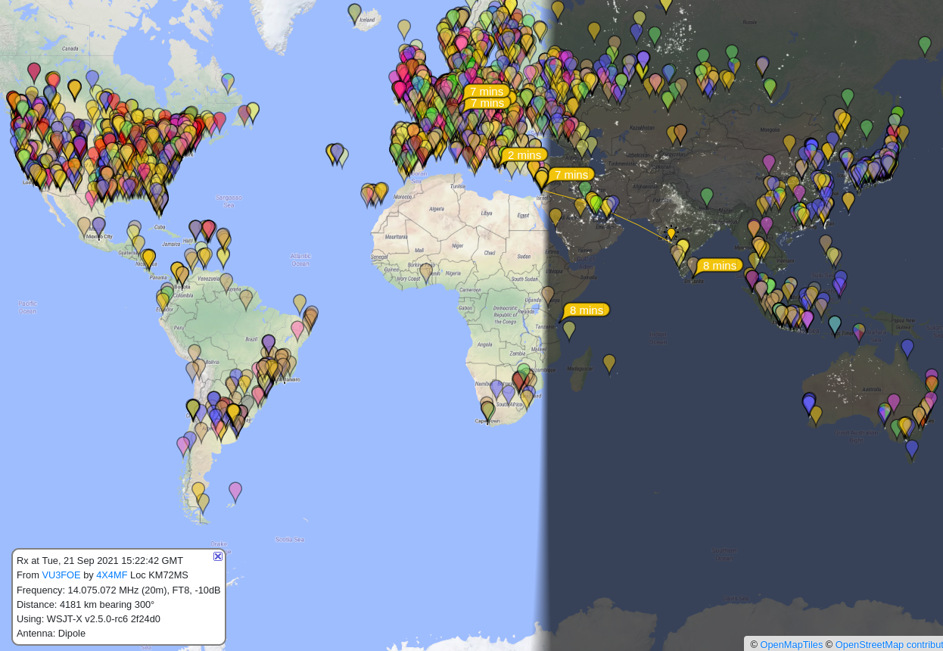
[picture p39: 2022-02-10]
RX-Reports/Screenshot_2021-09-21_21-00-12.png

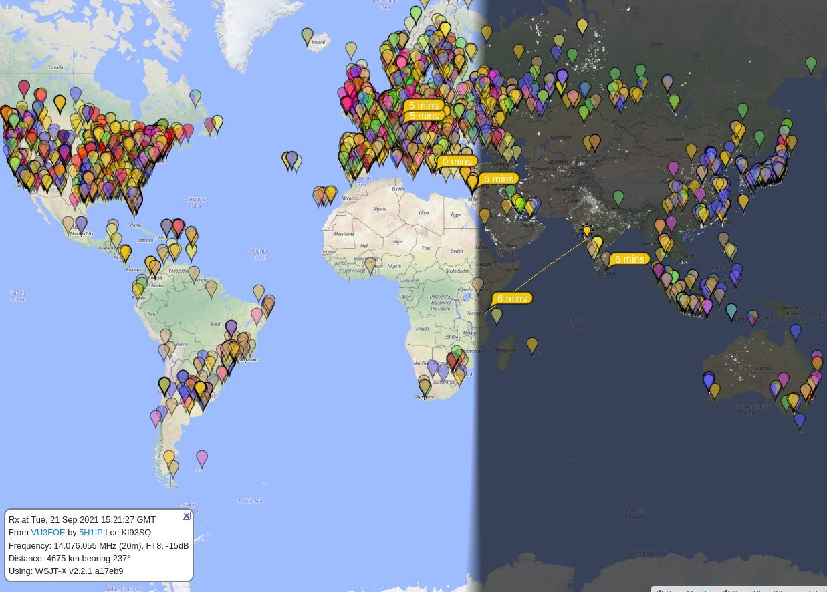
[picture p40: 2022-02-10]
RX-Reports/Screenshot_2021-09-21_20-58-25.png

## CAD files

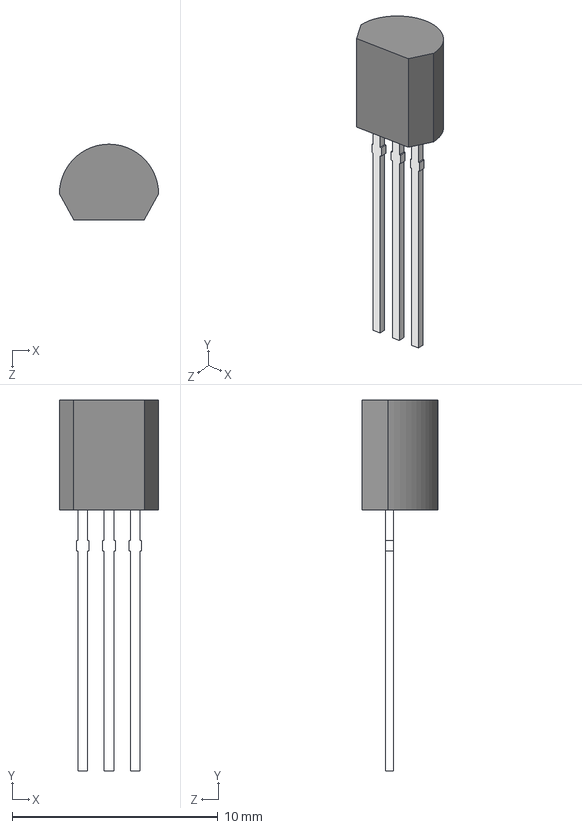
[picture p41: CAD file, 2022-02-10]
HF-PA-v3-Better-Regulator/models/LM78L05ACZ_NOPB.step
4.83 x 18.0 x 3.68 mm

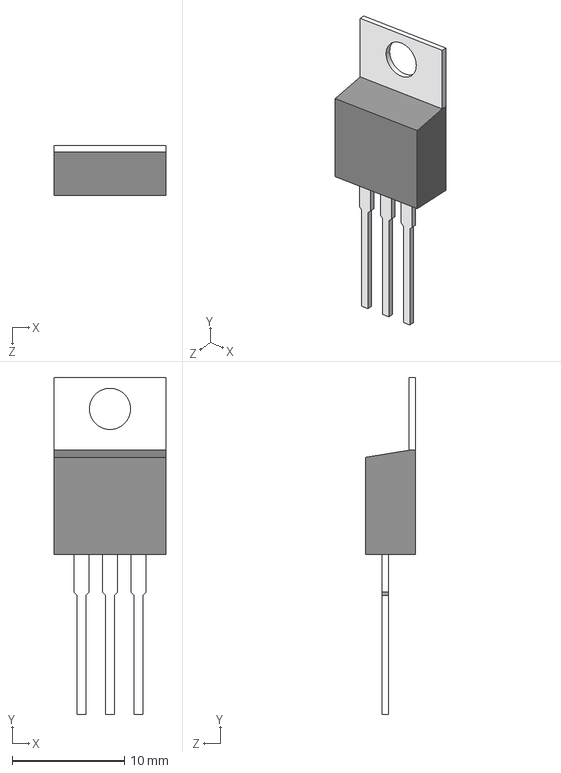
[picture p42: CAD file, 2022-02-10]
HF-PA-v3-No-Regulator/models/LM7805CT_NOPB.step
9.97 x 30.0 x 4.44 mm

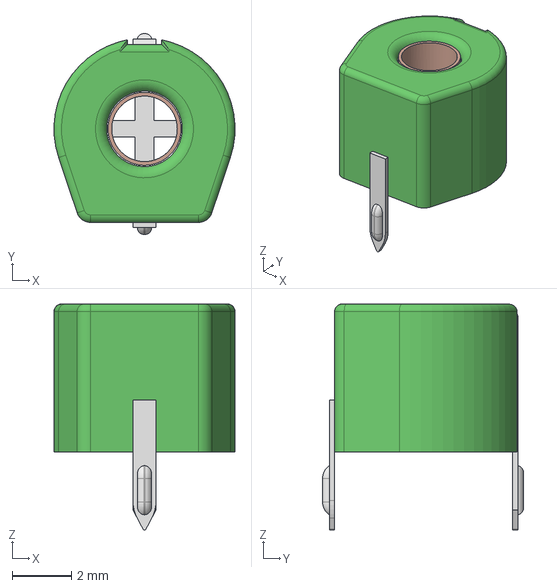
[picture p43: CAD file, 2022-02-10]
HF-PA-v3-Better-Regulator/models/Trimmer Cap - Green.stp
6.09 x 6.76 x 7.61 mm

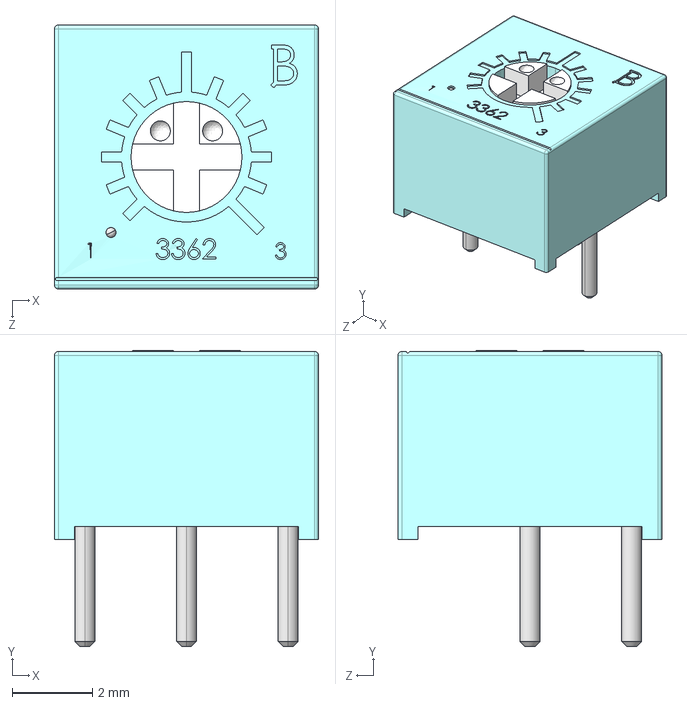
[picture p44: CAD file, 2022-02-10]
HF-PA-v3.1/models/3362P-1-102LF.STEP
6.60 x 7.40 x 6.60 mm

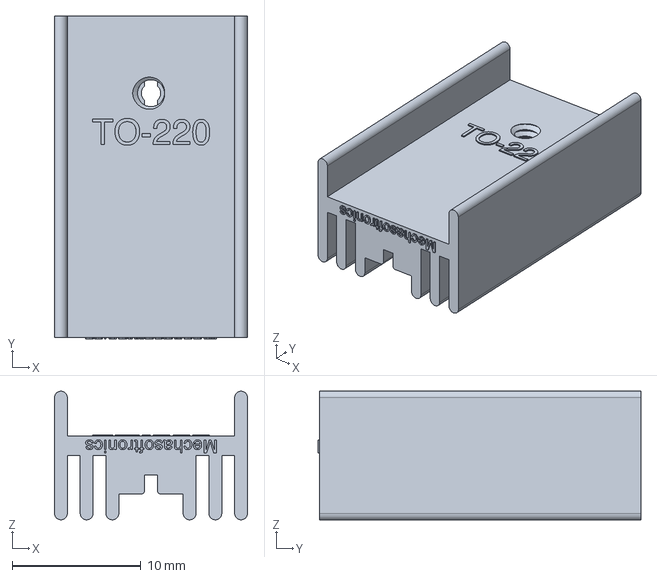
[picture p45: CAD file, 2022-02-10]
HF-PA-v3-Better-Regulator/models/heatsink_to-220.stp
15.0 x 25.1 x 10.0 mm

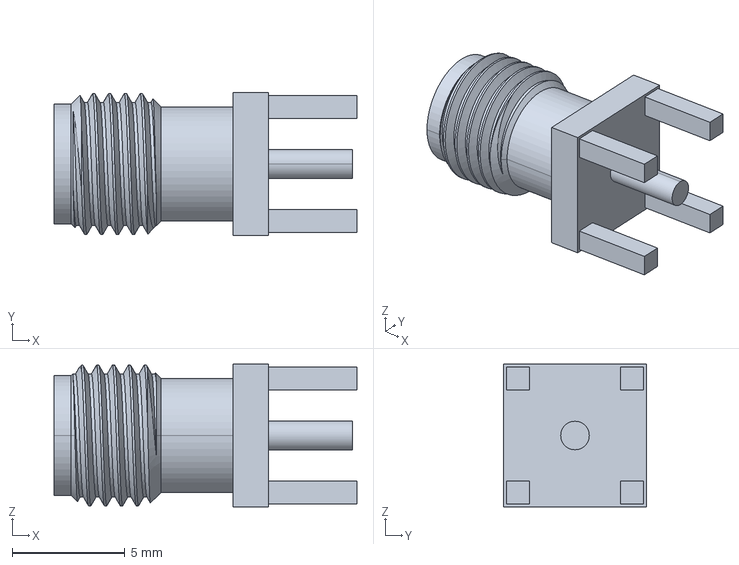
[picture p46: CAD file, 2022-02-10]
HF-PA-v3-Better-Regulator/models/901-144.stp
13.5 x 6.35 x 6.35 mm

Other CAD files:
HF-PA-v3-No-Regulator/models/Trimmer Cap - Yellow.stp
HF-PA-v3.1/models/Trimmer Cap - Yellow.stp
HF-PA-v3-Better-Regulator/models/Trimmer Cap - Yellow.stp
HF-PA-v3/models/Trimmer Cap - Yellow.stp

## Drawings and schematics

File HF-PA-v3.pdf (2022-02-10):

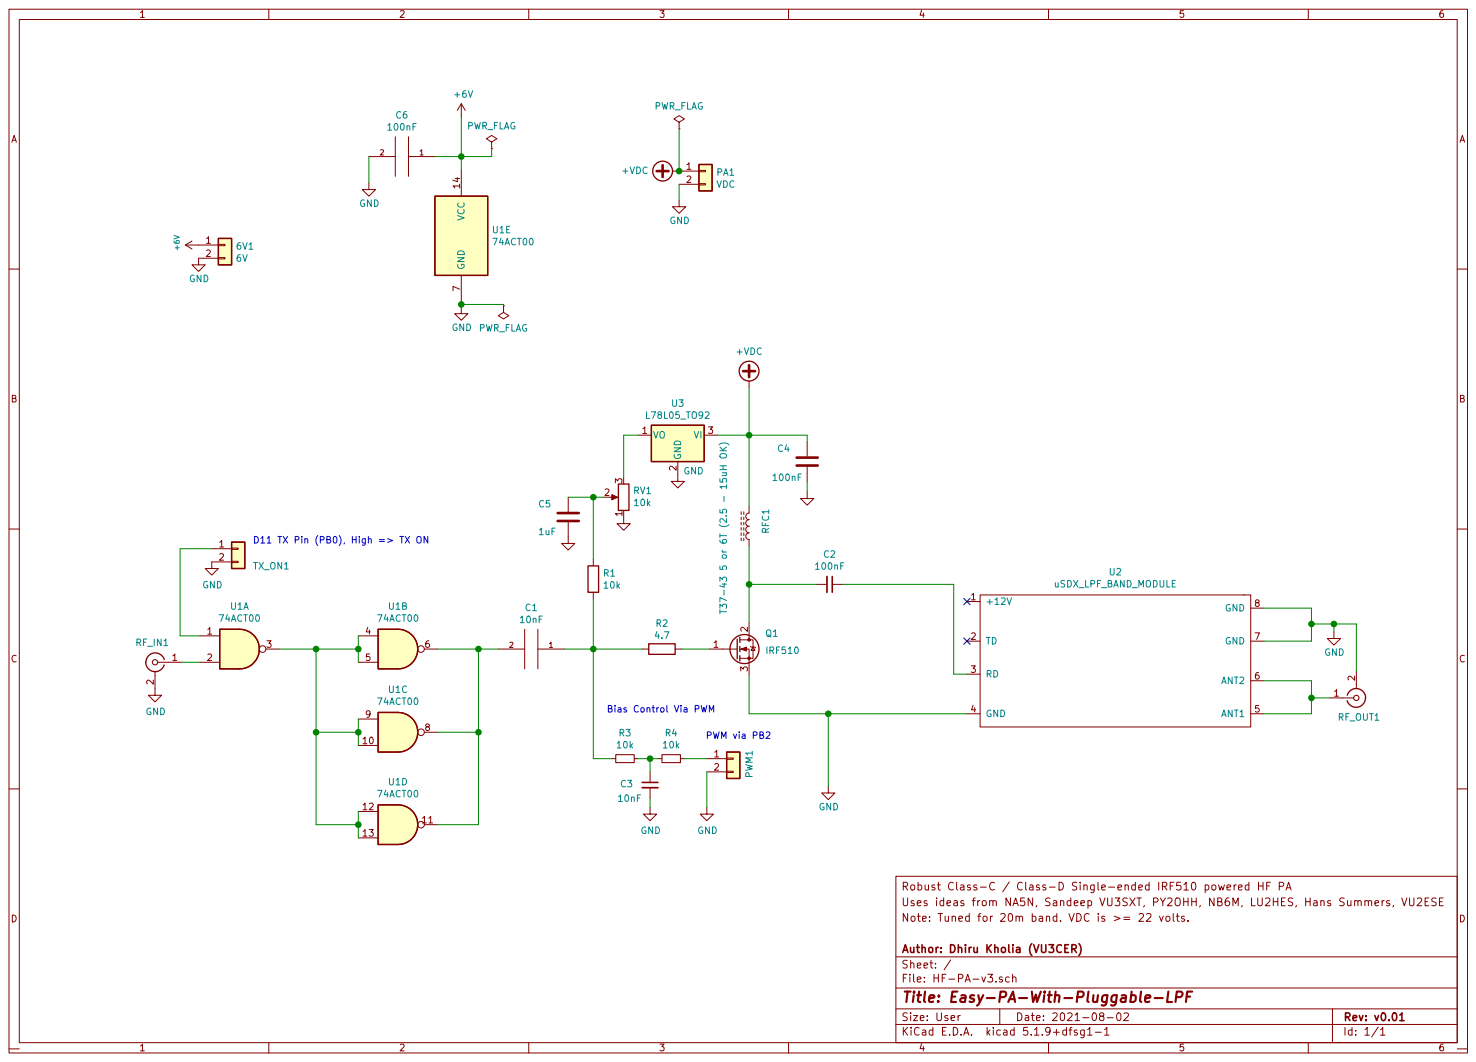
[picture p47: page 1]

100nF PWM via PB2 Bias Control Via PWM

D11 TX Pin (PB0), High => TX ON

Robust Class-C / Class-D Single-ended IRF510 powered HF PA
File: HF-PA-v3.sch Sheet: / Author: Dhiru Kholia (VU3CER) Note: Tuned for 20m band. VDC is >= 22 volts. Uses ideas from NA5N, Sandeep VU3SXT, PY2OHH, NB6M, LU2HES, Hans Summers, VU2ESE

Id: 1/1 Title: Easy-PA-With-Pluggable-LPF

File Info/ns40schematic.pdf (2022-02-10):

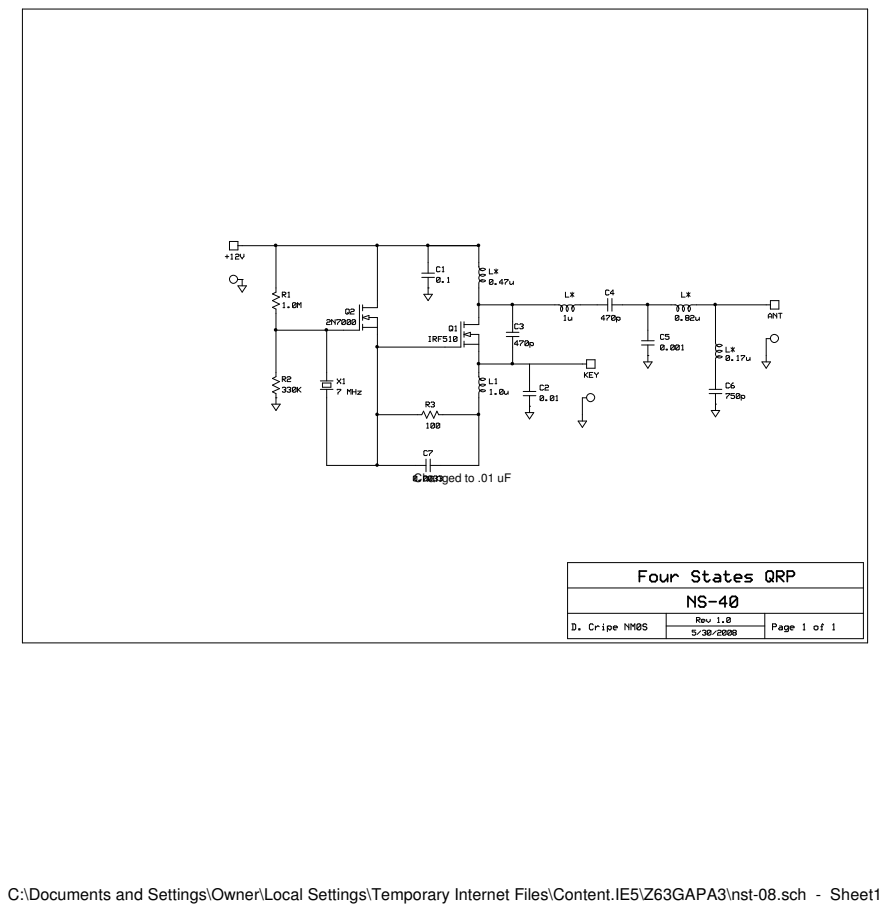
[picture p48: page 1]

Changed to .01 uFf

C:\Documents and Settings\Owner\Local Settings\Temporary Internet Files\Content.IE5\Z63GAPA3\nst-08.sch - Sheet1

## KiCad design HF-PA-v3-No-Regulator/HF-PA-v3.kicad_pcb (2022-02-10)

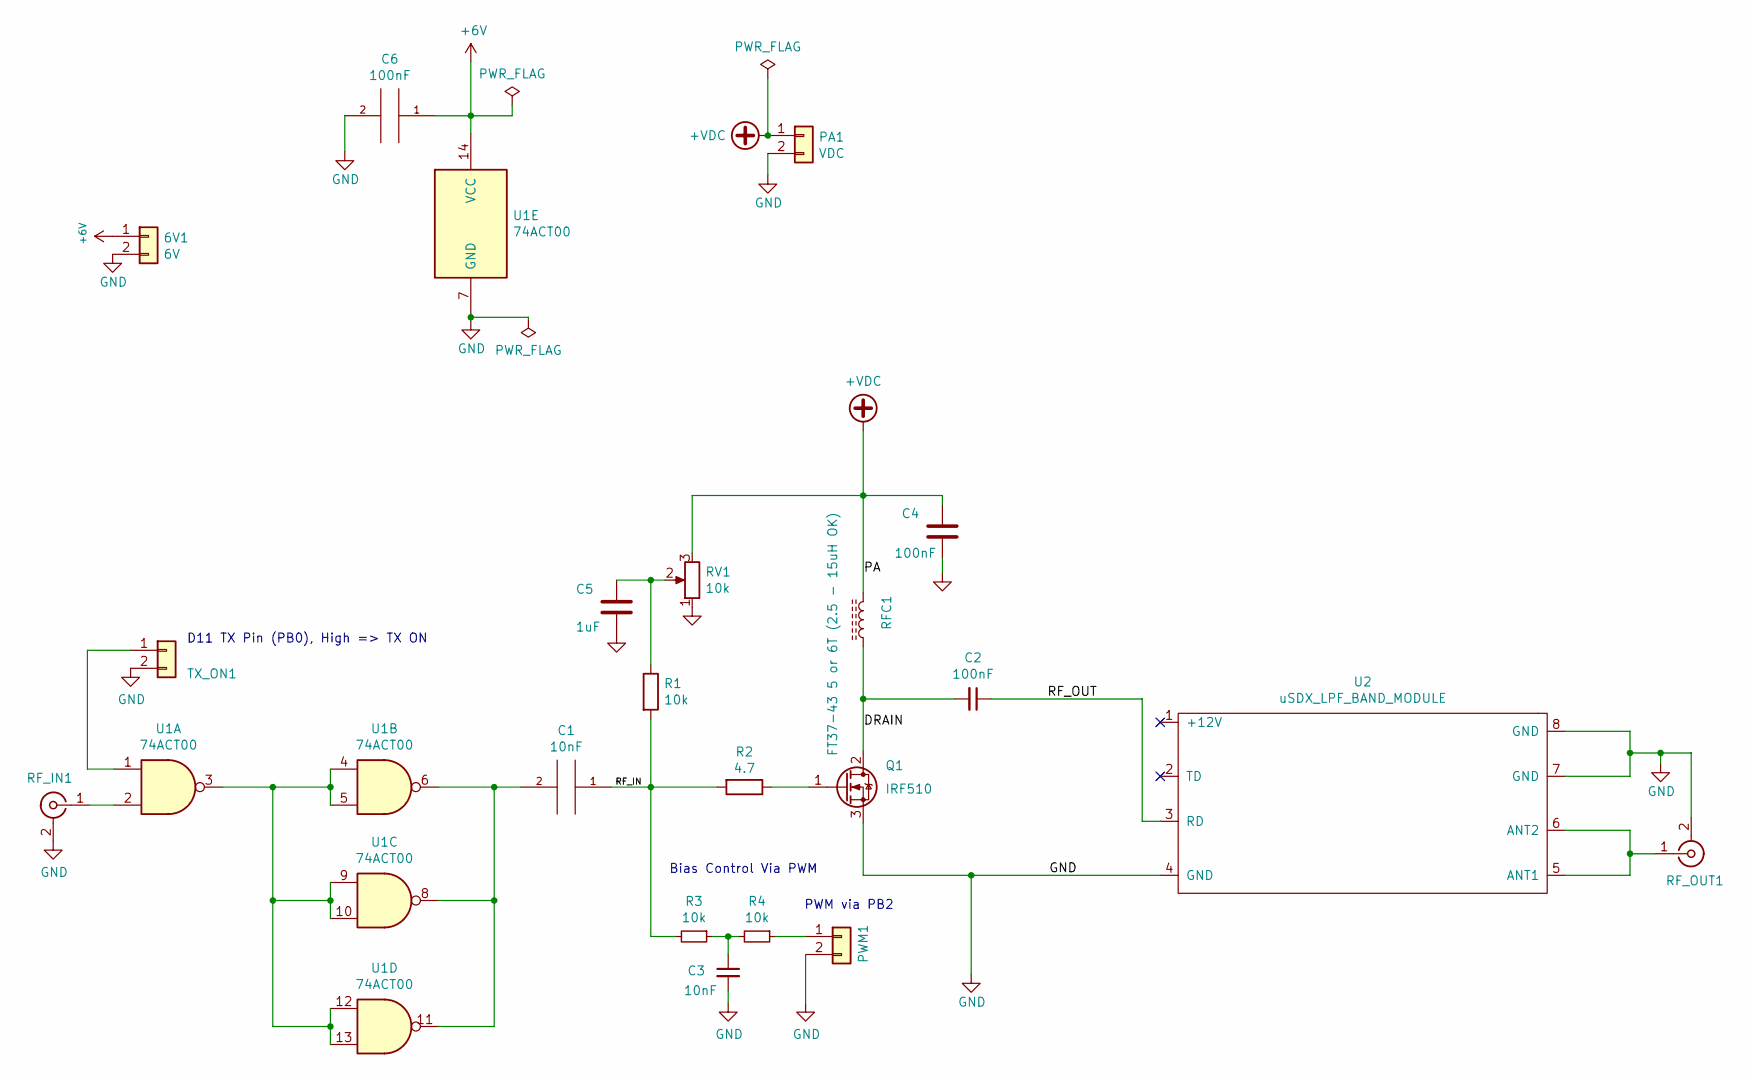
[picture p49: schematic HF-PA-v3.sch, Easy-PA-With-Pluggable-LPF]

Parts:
6V1: 6V; PinHeader_1x02_P2.54mm_Vertical
C1, C3: 10nF; C_Disc_D4.3mm_W1.9mm_P5.00mm
C2, C4, C6: 100nF; C_Disc_D4.3mm_W1.9mm_P5.00mm
C5: 1uF; C_Disc_D4.3mm_W1.9mm_P5.00mm
PA1: VDC; PinHeader_1x02_P2.54mm_Vertical
PWM1: Conn_01x02; PinHeader_1x02_P2.54mm_Vertical
Q1: IRF510; TO-220-3_Vertical
R1, R3, R4: 10k; R_Axial_DIN0207_L6.3mm_D2.5mm_P2.54mm_Vertical
R2: 4.7; R_Axial_DIN0207_L6.3mm_D2.5mm_P2.54mm_Vertical
RFC1: FT37-43 5 or 6T (2.5 - 15uH OK); L_Toroid_Vertical_L10.0mm_W5.0mm_P5.08mm
RF_IN1: Conn_Coaxial; SMA_Amphenol_901-144_Vertical
RF_OUT1: Conn_Coaxial; SMA_Amphenol_901-144_Vertical
RV1: 10k; Potentiometer_Bourns_3386P_Vertical
TX_ON1: Conn_01x02; PinHeader_1x02_P2.54mm_Vertical
U1: 74ACT00; DIP-14_W7.62mm_LongPads
U2: uSDX_LPF_BAND_MODULE; uSDX_LPF_Band_Module

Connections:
+6V: 6V1.1, C6.1, U1.14 (VCC)
+VDC: C4.1, PA1.1, RFC1.2, RV1.3
/DRAIN: C2.2, Q1.2 (D), RFC1.1
/RF_IN: C1.1, R1.2, R2.2, R3.2
/RF_OUT: C2.1, U2.3 (RD)
GND: 6V1.2, C3.2, C4.2, C5.2, C6.2, PA1.2, PWM1.2, Q1.3 (S), RF_IN1.2 (Ext), RF_OUT1.2 (Ext), RV1.1, TX_ON1.2, U1.7 (GND), U2.4 (GND), U2.7 (GND), U2.8 (GND)
unnamed: C1.2, U1.6, U1.8, U1.11
unnamed: C3.1, R3.1, R4.2
unnamed: C5.1, R1.1, RV1.2
unnamed: PWM1.1, R4.1
unnamed: Q1.1 (G), R2.1
unnamed: RF_IN1.1 (In), U1.2
unnamed: RF_OUT1.1 (In), U2.5 (ANT1), U2.6 (ANT2)
unnamed: TX_ON1.1, U1.1
unnamed: U1.3, U1.4, U1.5, U1.9, U1.10, U1.12, U1.13

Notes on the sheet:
D11 TX Pin (PB0), High => TX ON
Bias Control Via PWM
PWM via PB2

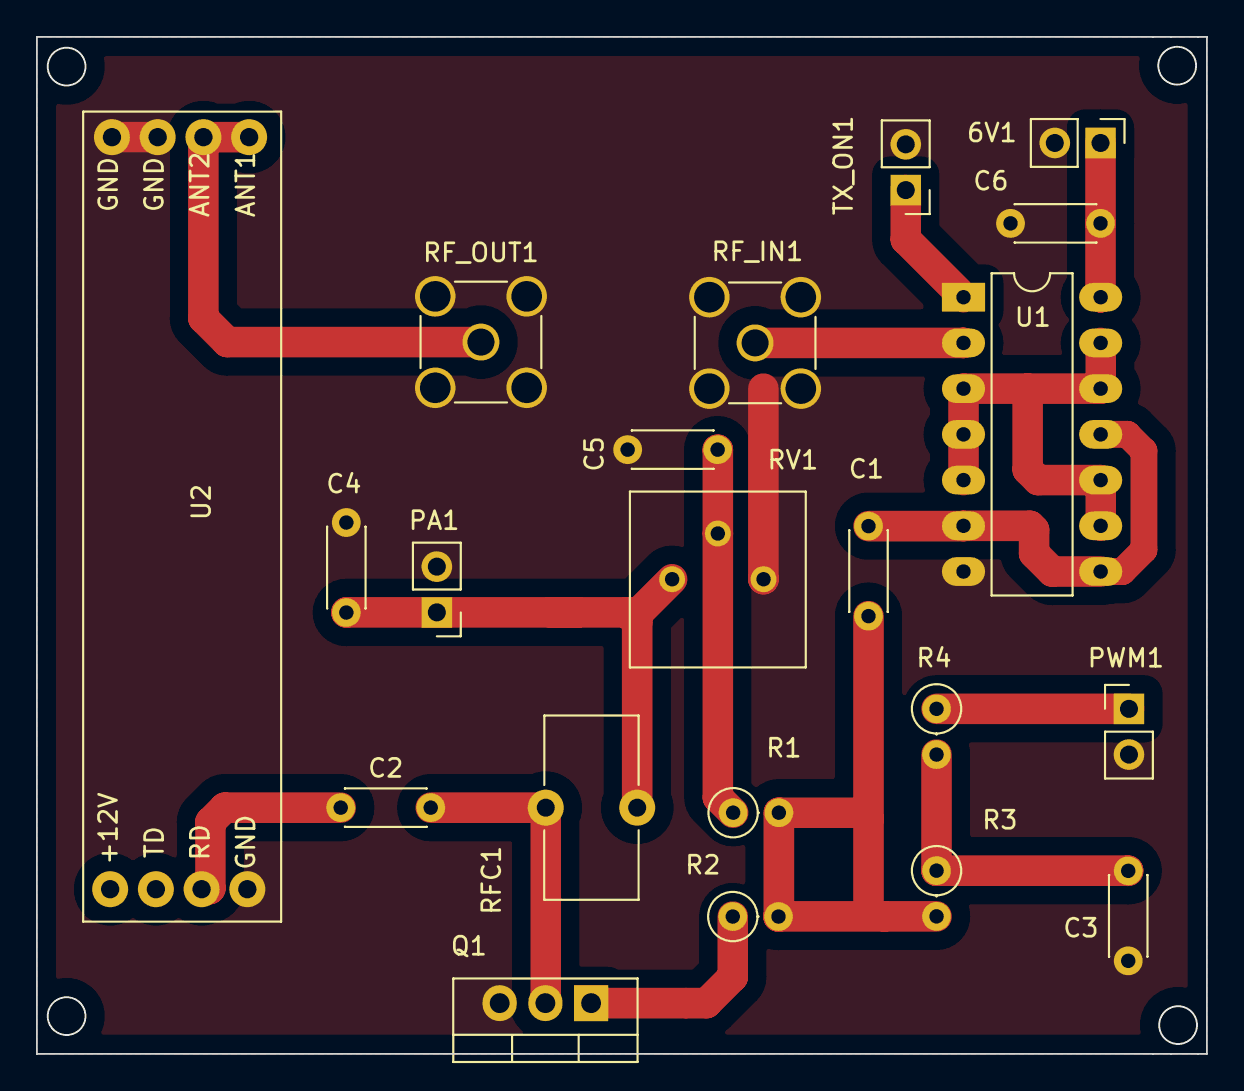
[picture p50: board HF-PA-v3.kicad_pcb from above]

Board: 2 copper layers, 65.0 x 56.5 mm, 21 parts (0 on the bottom side), 15 nets.
